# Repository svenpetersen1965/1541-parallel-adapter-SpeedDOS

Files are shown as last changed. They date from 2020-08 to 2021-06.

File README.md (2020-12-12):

# 1541-parallel-adapter-SpeedDOS
This is a reliable and easy to build parallel User Port Adapter for the Commodore 1541/1541-II for SpeedDOS

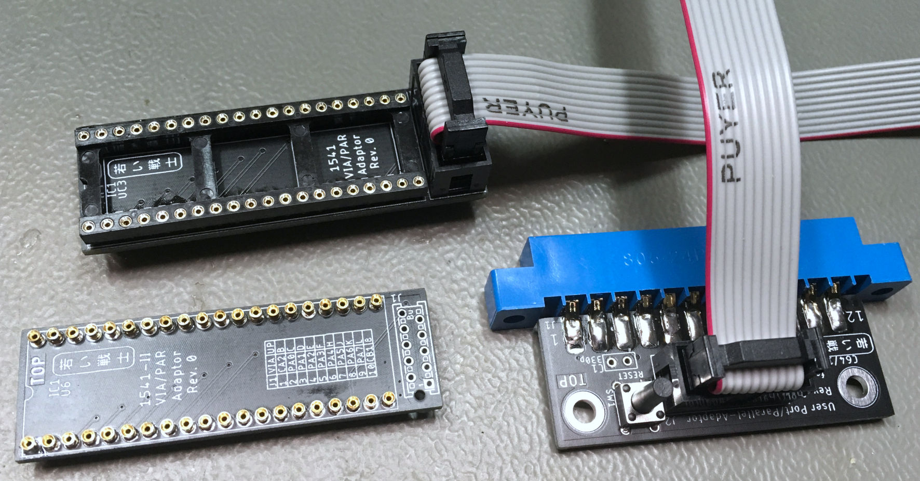
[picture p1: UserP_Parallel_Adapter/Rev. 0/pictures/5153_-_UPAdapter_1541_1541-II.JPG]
SpeedDOS parallel interface


The project consists out of a user port module with a 3D printed case, which also includes a RESET button for the C64. 

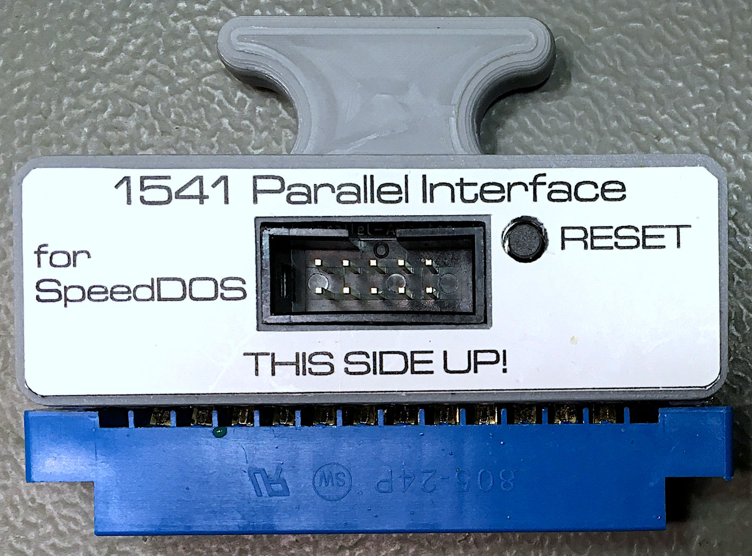
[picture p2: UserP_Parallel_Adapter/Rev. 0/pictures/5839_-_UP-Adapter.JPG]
SpeedDOS parallel interface


There are two different VIA adapters for the 1541 and a low profile one for the narrower sapce in the 1541-II.

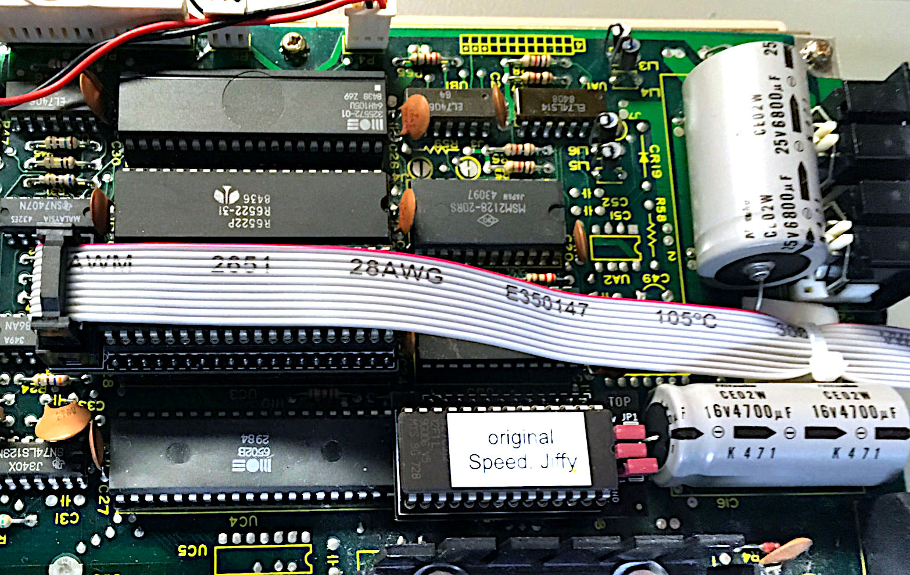
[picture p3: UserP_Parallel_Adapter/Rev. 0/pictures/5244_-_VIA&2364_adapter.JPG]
SpeedDOS VIA adapter 1541


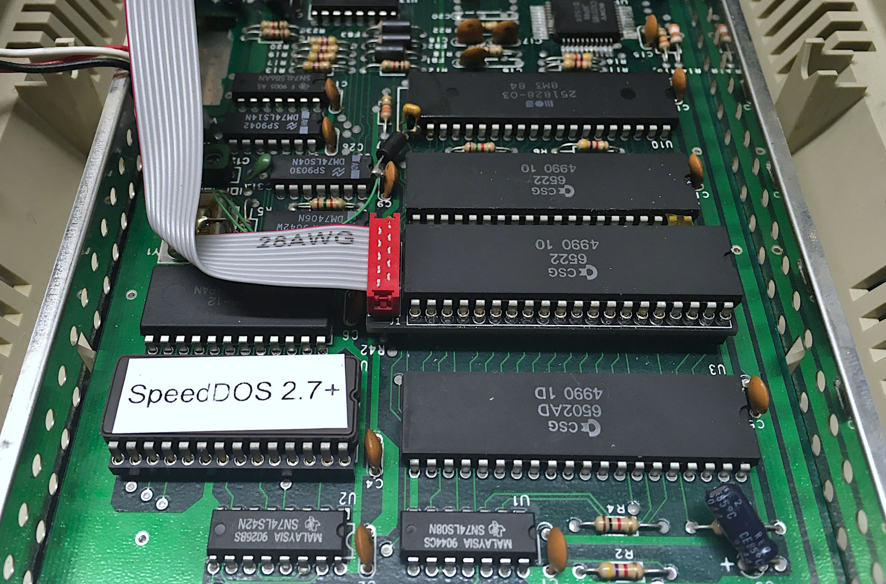
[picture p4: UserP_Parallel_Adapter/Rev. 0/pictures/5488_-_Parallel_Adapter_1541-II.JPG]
SpeedDOS VIA adapter 1541


BOM Values:
* 1541 Adapter (cable included): 4.91€ (28.06.2020)
* 1541-II Adapter (cable included): 3.30€ (10.12.2020)
* User Port Adapter (no case): 4.65€ (28.06.2020)

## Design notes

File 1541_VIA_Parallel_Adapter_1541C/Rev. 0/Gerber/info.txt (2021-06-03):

      
       Board: VIA_PAR_Adapter_1541C
       Rev.:  0
  
       Files:
       ======
  
       All Gerber files are generated in extended gerber format (RS274X)
       *.TOP        : Film top copper
       *.BOT        :  -"- bottom copper
       *.STC        :  -"- top soldermask 
       *.STS        :  -"- bottom soldermask
       *.PLC        :  -"- silk screen top
       *.PLS        :  -"- silk screen bottom
       *.DK         : Drills plated Through (Excellon)
       *.NDK        : Drills not plated Through (Excellon)
       *.OUT        : Board outline

       Board Size:
       ===========
       Length     :   65.0 mm
       Width      :   21.5 mm
       Thickness  :   1.6 mm
       Material   :   FR 4
       Copper     :   35 um
       Surface    :   HASL
       
       Remarks:
       ========
       minimum drill: 0.35mm
       minimum width: 8 mil
       minimum distance: 6 mil

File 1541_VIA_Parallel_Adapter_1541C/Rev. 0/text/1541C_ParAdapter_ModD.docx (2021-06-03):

Commodore 1541 VIA/Parallel-Adapter for 1541C Rev. 0

Module Description

# Introduction

This adapter board serves as a VIA (6522) adapter for a parallel connection for SpeedDOS in conjunction with a suitable ribbon cable and the User Port Parallel-Adapter (Project 150).

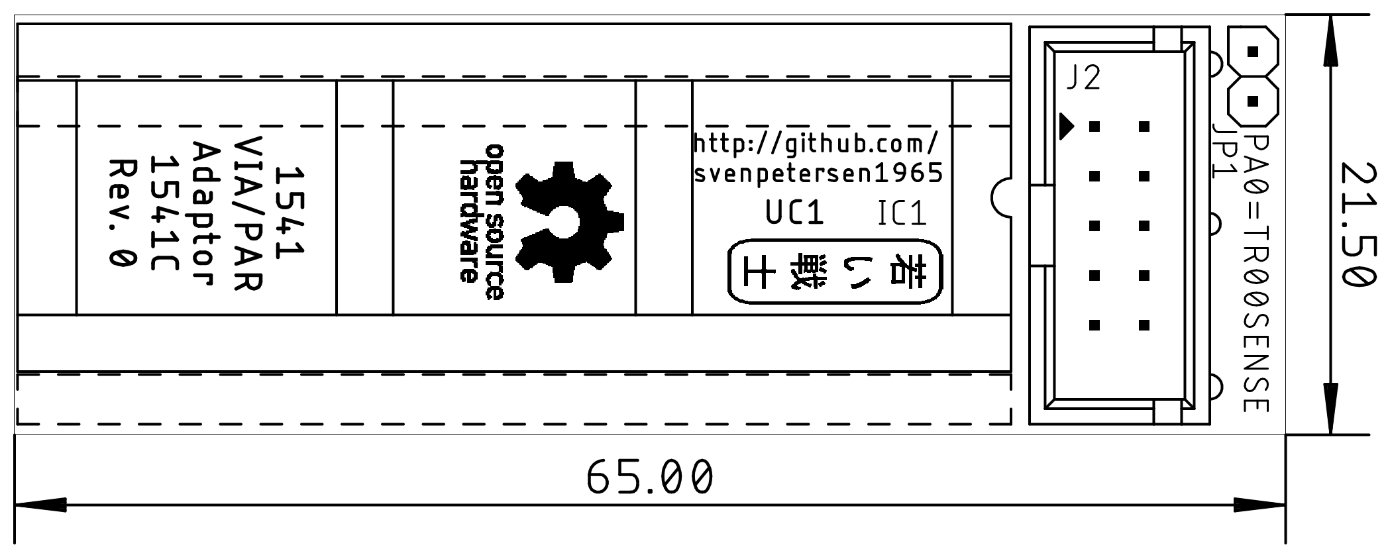
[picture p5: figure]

Figure 1: Dimensions

The box connector (2x5 way, 2.54mm pitch) has the following pinout:

VIA (pin) | J2 | J2 | VIA (pin)
CA2 (39) | 1 | 2 | PA0 (2)
PA1 (3) | 3 | 4 | PA2 (4)
PA3 (5) | 5 | 6 | PA4 (6)
PA5 (7) | 7 | 8 | PA6 (8)
PA7 (9) | 9 | 10 | CB1 (18)

The via for the parallel data transmission in a 1541C is UC1. The Jumper JP1 connects the signal PA0 to the signal TR00SENSE, which is (probably) required for the original firmware.

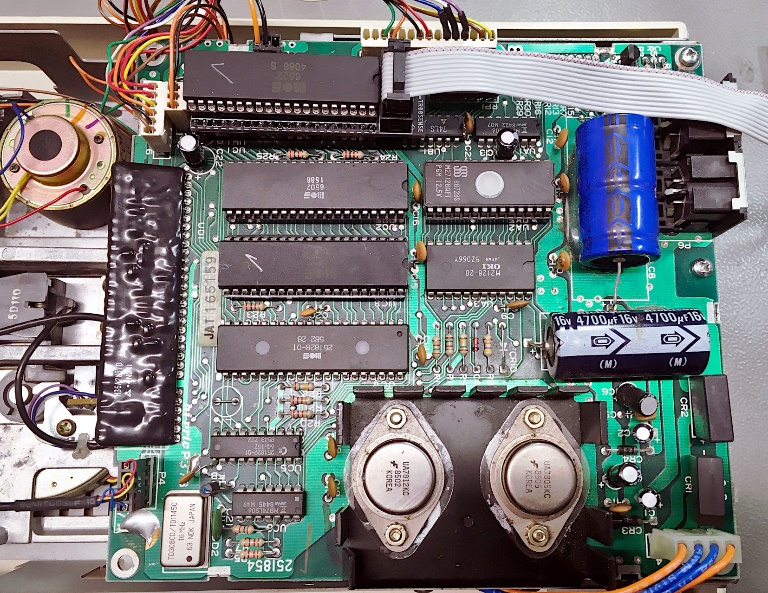
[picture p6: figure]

Figure 2: : VIA-Parallel-Adapter installed in a 1541C

# Installation

Three issues have to be taken care of, when installing the VIA-Parallel-Adapter:

- The VIA (UC1) should be socketed
- The adapter has to be oriented properly (align the notch of the IC, the adapter and the socket on the 1541C PCB
- The pins of box connector on the solder side must not make contact with any component leads

The latter issue can be caused by the leads of a 100n capacitor, which can be replaced with a smaller, modern capacitor. The adapter has to sit firmly in the socket, though.

The ribbon cable has two 2x5 (ribbon cable) IDC connectors. The one, that goes inside the 1541C is the one without a strain relief. The header connecting to the User Port Adapter does require the strain relief, though.

It is a good idea to secure the ribbon cable with an adhesive cable post and a cable tie for strain relief, after the configuration is fully functional. A ribbon cable exiting the case through the breakout for the fuse is pretty common, I did not experience any problems with it, but one person reported a possible source of problems, here.

An alternative way of exiting the case is the left side of the case. A breakout for the ribbon cable has to be filed into the case, though.

The cable making with IDC connectors does not require any special tools, except a (small) vice for compressing the connector after the ribbon cable was inserted properly. In case you don not feel comfortable with this work, consult this write up about cable making: http://tech.guitarsite.de/cable_making.html#Ribbon%20Cables

# Assembly

The Assembly of the VIA-Parallel-Adapter is fairly simple. The precision round pin headers on the solder side need to be aligned to be straight and in the proper distance. For this purpose, the cut strips have to be inserted into the DIP-socket before soldering. Their alignment needs to be checked. They should be fully inserted into the socket and the PCB should be perpendicular. After soldering the pin stripes, the DIP-40 socket can be removed and soldered in on the top side. Some of soldered pins of the pin strips might require to be shortened. The DIP-40 socket should sit straight on the PCB.

Finally, the box connector can be soldered.

The pins of the precision pin strips are pretty delicate and brittle. They should not be bent much, so care must be taken before and while installing them in the socket of the 1541. Square headers must not be used instead, because those might break the sockets and do not sit well in the socket, either.

# Revision History

## Rev. 0

- Prototypes preliminarily tested in a 1541.

1541C_ParAdapter_ModD.docx 07.05.2021 16:39 Drafted by Sven Petersen Page 2 of 2 Doc.-No.: 178-6-01-00

1541C_ParAdapter_ModD.docx 07.05.2021 16:39 Drafted by Sven Petersen Page 1 of 1 Doc.-No.: 000-6-00-00

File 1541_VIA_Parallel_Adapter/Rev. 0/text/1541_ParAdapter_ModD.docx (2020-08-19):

Commodore 1541 VIA/Parallel-Adapter Rev. 0

Module Description

# Introduction

This adapter board serves as a VIA (6522) adapter for a parallel connection for SpeedDOS in conjunction with a suitable ribbon cable and the User Port Parallel-Adapter (Project 150).

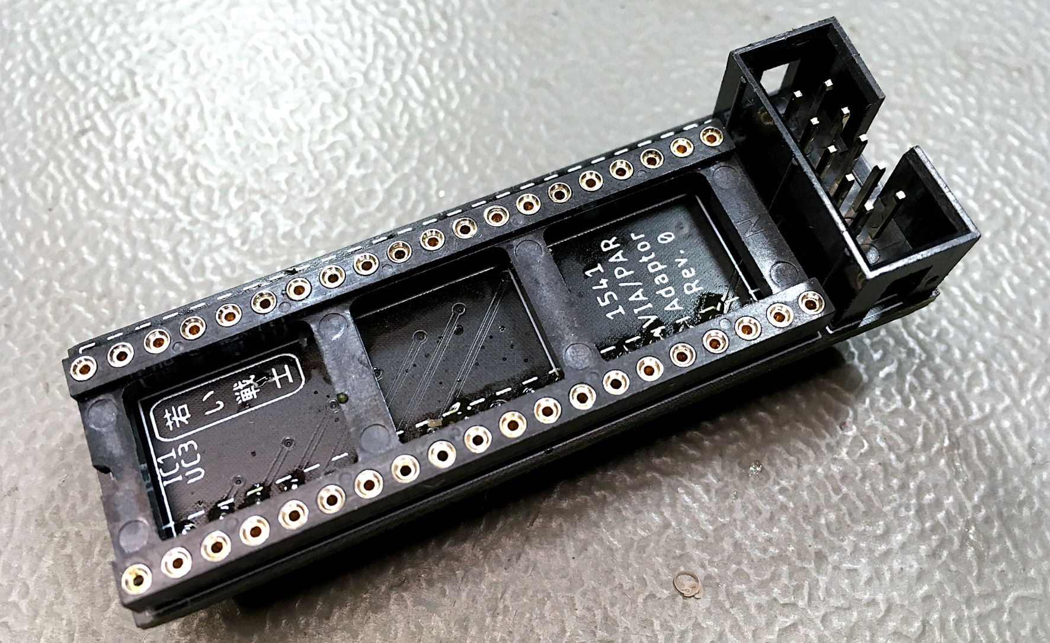
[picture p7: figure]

Figure 1: Commodore 1541 VIA/Parallel-Adapter

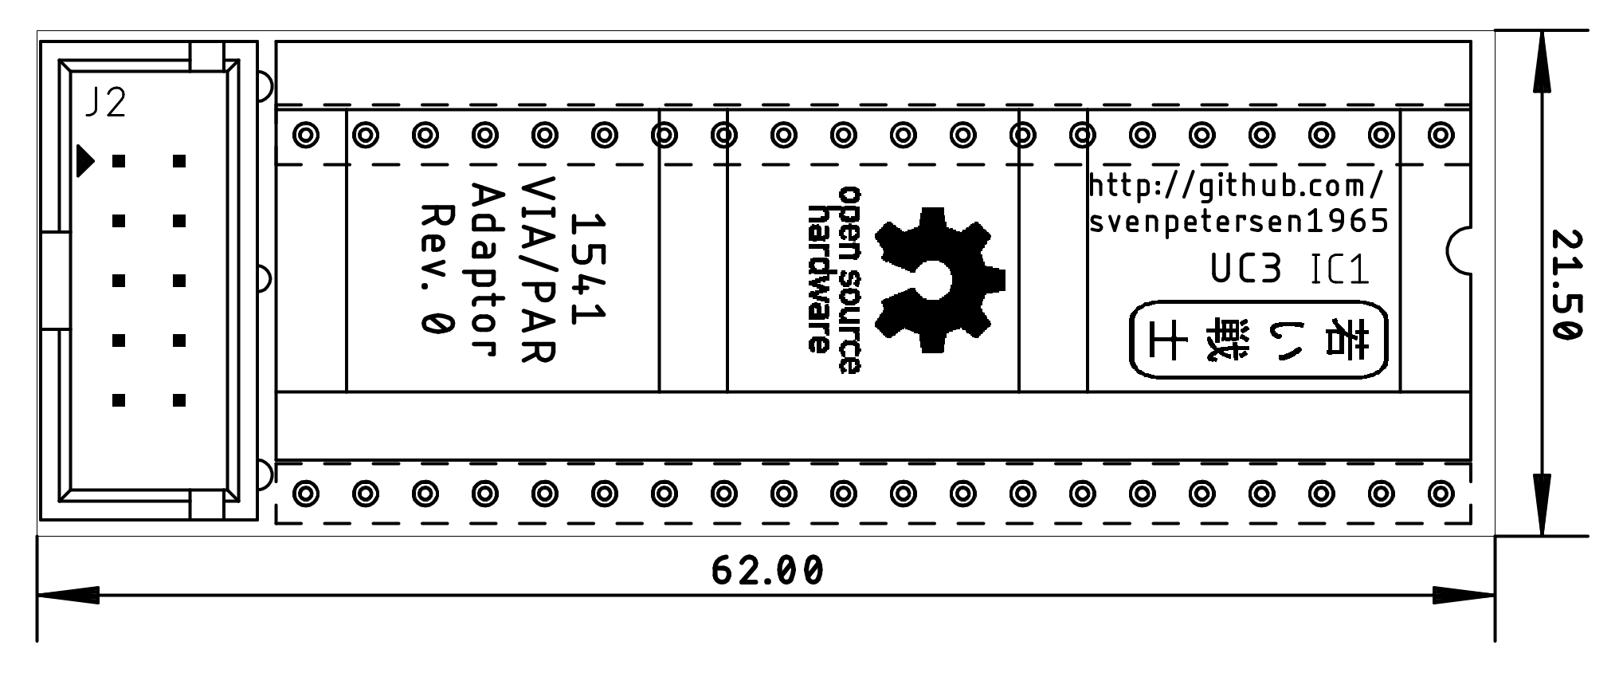
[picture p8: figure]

Figure 2: Dimensions

The box connector (2x5 way, 2.54mm pitch) has the following pinout:

VIA (pin) | J2 | J2 | VIA (pin)
CA2 (39) | 1 | 2 | PA0 (2)
PA1 (3) | 3 | 4 | PA2 (4)
PA3 (5) | 5 | 6 | PA4 (6)
PA5 (7) | 7 | 8 | PA6 (8)
PA7 (9) | 9 | 10 | CB1 (18)

The via for the parallel data transmission in a 1541 is UC3.

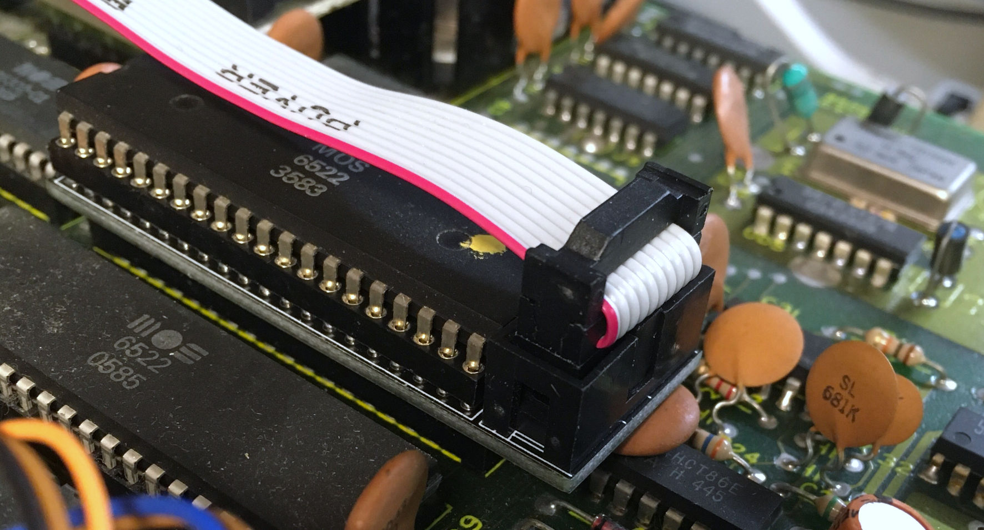
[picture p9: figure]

Figure 3: VIA-Parallel-Adapter installed in a 1541

# Installation

Three issues have to be taken care of, when installing the VIA-Parallel-Adapter:

- The VIA (UC3) should be socketed
- The adapter has to be oriented properly (align the notch of the IC, the adapter and the socket on the 1541 PCB
- The pins of box connector on the solder side must not make contact with any component leads

The latter issue can be caused by the leads of C28. This is a 100n capacitor, which can be replaced with a smaller, modern capacitor. In case it is a disc capacitor like in Figure 3, it can be bent over. The adapter has to sit firmly in the socket, though.

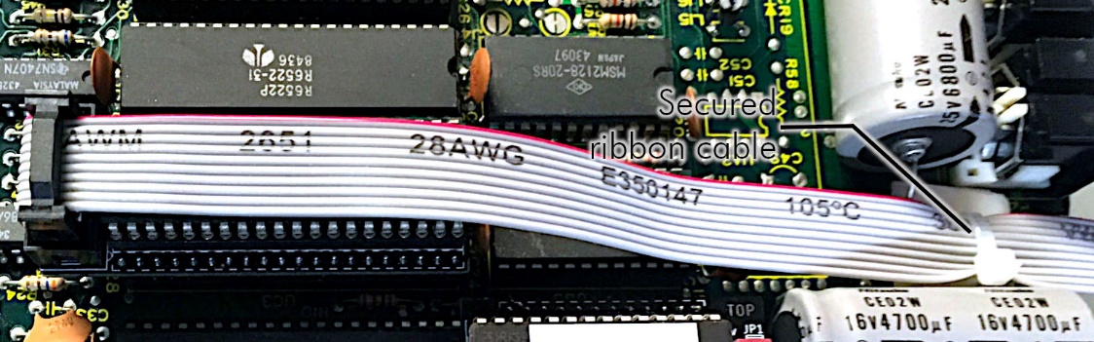
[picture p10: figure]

Figure 4: Secured ribbon cable

It is a good idea to secure the ribbon cable with an adhesive cable post and a cable tie for strain relief, after the configuration is fully functional (Figure 4). A ribbon cable exiting the case through the breakout for the fuse is pretty common, I did not experience any problems with it, but one person reported a possible source of problems, here.

An alternative way of exiting the case is the left side of the case. A breakout for the ribbon cable has to be filed into the case, though.

The cable making with IDC connectors does not require any special tools, except a (small) vice for compressing the connector after the ribbon cable was inserted properly. In case you don not feel comfortable with this work, consult this write up about cable making: http://tech.guitarsite.de/cable_making.html#Ribbon%20Cables

# Assembly

The Assembly of the VIA-Parallel-Adapter is fairly simple. The precision round pin headers on the solder side need to be aligned to be straight and in the proper distance. For this purpose, the cut strips have to be inserted into the DIP-socket before soldering. Their alignment needs to be checked. They should be fully inserted into the socket and the PCB should be perpendicular. After soldering the pin stripes, the DIP-40 socket can be removed and soldered in on the top side. Some of soldered pins of the pin strips might require to be shortened. The DIP-40 socket should sit straight on the PCB.

Finally, the box connector can be soldered.

The pins of the precision pin strips are pretty delicate and brittle. They should not be bent much, so care must be taken before and while installing them in the socket of the 1541. Square headers must not be used instead, because those might break the sockets and do not sit well in the socket, either.

# Revision History

## Rev. 0

- Prototypes fully functional. For testing consult the documentation of the User Port/Parallel Adapter (Project 150).

1541_ParAdapter_ModD.docx 19.08.2020 14:08 Drafted by Sven Petersen Page 2 of 2 Doc.-No.: 148-6-01-00

1541_ParAdapter_ModD.docx 19.08.2020 14:08 Drafted by Sven Petersen Page 1 of 1 Doc.-No.: 000-6-00-00

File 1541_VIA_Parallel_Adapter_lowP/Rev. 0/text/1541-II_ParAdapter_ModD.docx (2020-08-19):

Commodore 1541-II VIA/Parallel-Adapter Rev. 0

Module Description

# Introduction

This adapter board serves as a VIA (6522) adapter for a parallel connection for SpeedDOS in conjunction with a suitable ribbon cable and the User Port Parallel-Adapter (Project 150).

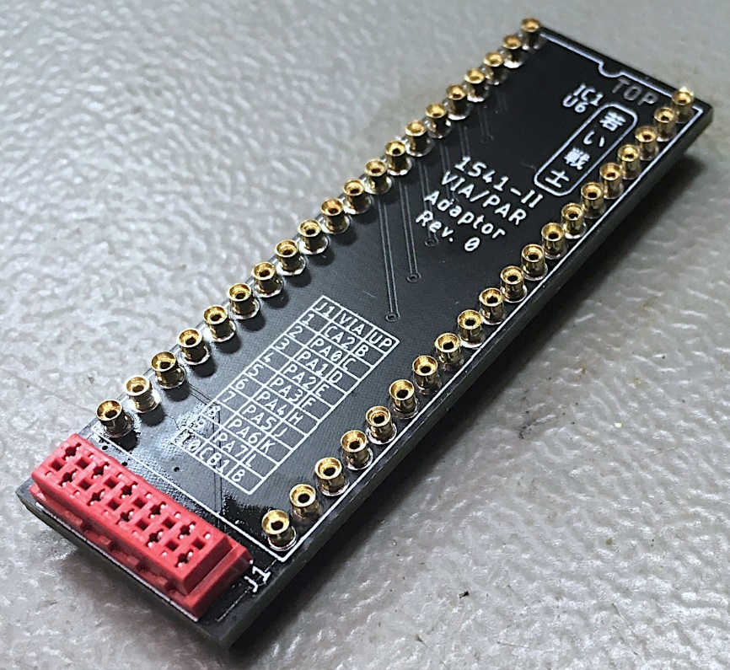
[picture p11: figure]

Figure 1: Commodore 1541-II VIA/Parallel-Adapter

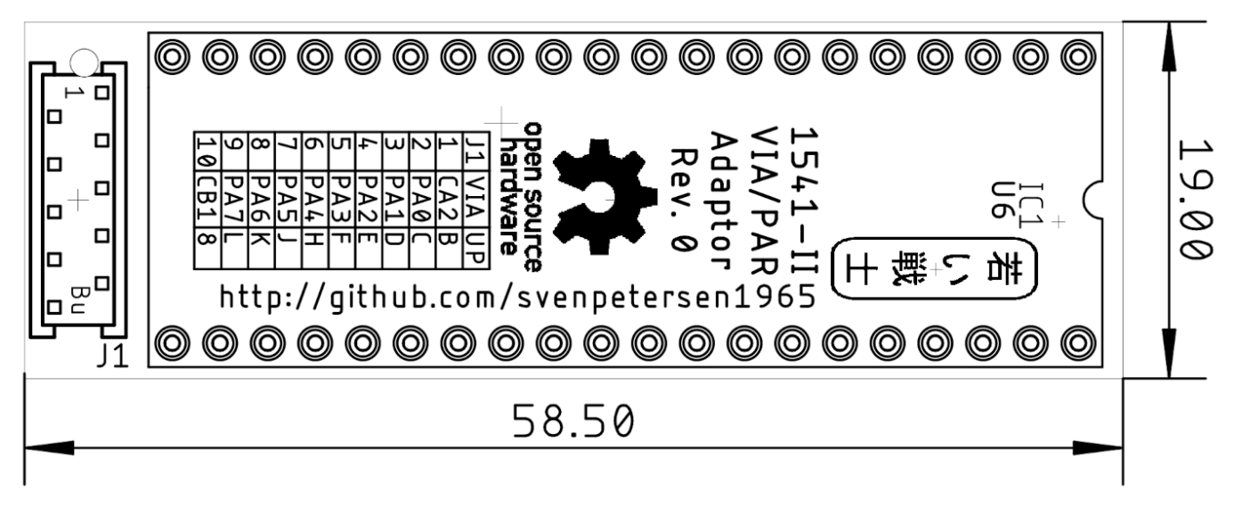
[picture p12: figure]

Figure 2: Dimensions

The microMatch connector (10 way) has the following pinout:

VIA (pin) | J2 | J2 | VIA (pin)
CA2 (39) | 1 | 2 | PA0 (2)
PA1 (3) | 3 | 4 | PA2 (4)
PA3 (5) | 5 | 6 | PA4 (6)
PA5 (7) | 7 | 8 | PA6 (8)
PA7 (9) | 9 | 10 | CB1 (18)

The via for the parallel data transmission in a 1541 is U6.

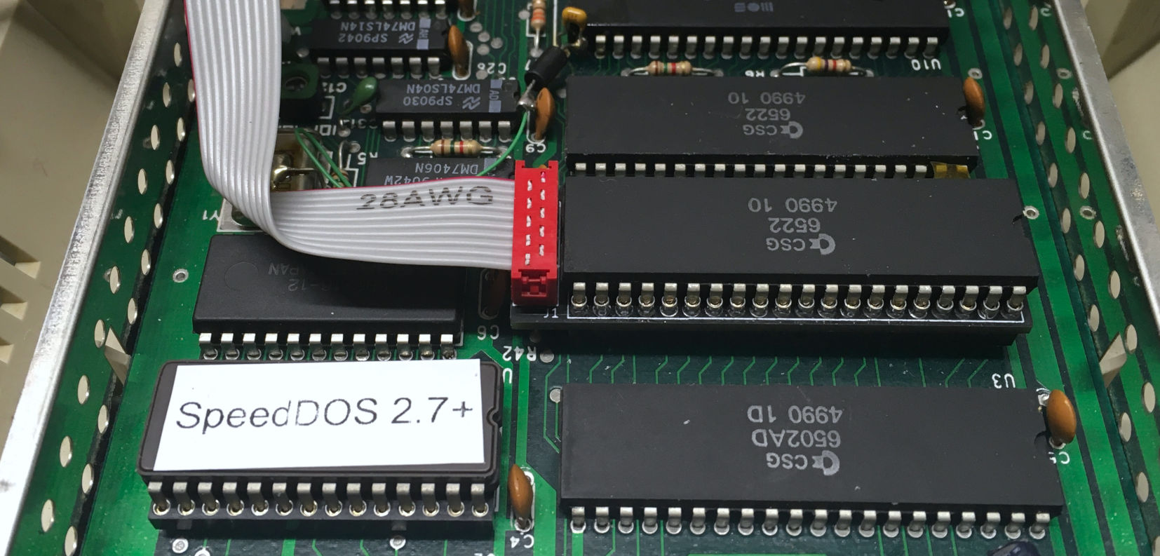
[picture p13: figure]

Figure 3: VIA-Parallel-Adapter installed in a 1541-II

# Installation

Four issues have to be taken care of, when installing the VIA-Parallel-Adapter:

- The VIA (U6) should be socketed
- The adapter has to be oriented properly (align the notch of the IC, the adapter and the socket on the 1541-II PCB
- The pins of microMatch connector on the solder side must not make contact with any component leads.
- Pin 2 (PA0) of U6 is connected to GND, which is not required for proper operation (not even with the original Kernal!). This prevents a proper function of the parallel adapter. Pin 2 must either be cut off, filed down (a bit) and insulated (Figure 4) or the trace between pin 1 and pin 2 of U6 must be cut.

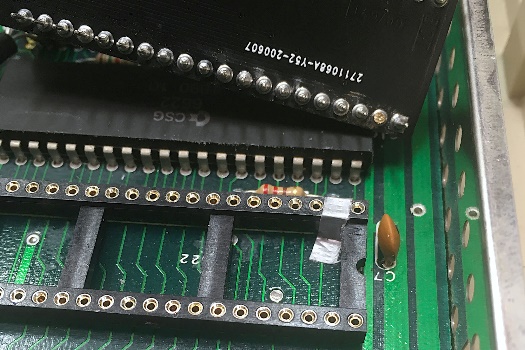
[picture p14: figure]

Figure 4: Shortened pin 2 and insulated socket

It is a good idea to secure the ribbon cable with an adhesive cable post and a cable tie for strain relief, after the configuration is fully functional. A ribbon cable exiting the case through the breakout for the fuse is pretty common, I did not experience any problems with it, but one person reported a possible source of problems, here.

An alternative way of exiting the case is the left side of the case. A breakout for the ribbon cable has to be filed into the case, though.

The cable making with IDC connectors does not require any special tools, except a (small) vice for compressing the connector after the ribbon cable was inserted properly. In case you don not feel comfortable with this work, consult this write up about cable making: http://tech.guitarsite.de/cable_making.html#Ribbon%20Cables

# Assembly

The low-profile property of the adapter requires precision round pin sockets. They are usually pretty hard to source and expensive. In July 2020, they were about $10 plus shipping for 50 each on Ebay USA. It is pretty cheap and easy to salvage them from a precision pin DIP-40 socket (40 pin sockets for less than $1!). The pin sockets can be popped out of a precision pin socket by applying slight pressure from the bottom side on the “shoulders” of the pin socket with a suitable tweezer (Figure 5). This takes less than 2 minutes per 40 pins.

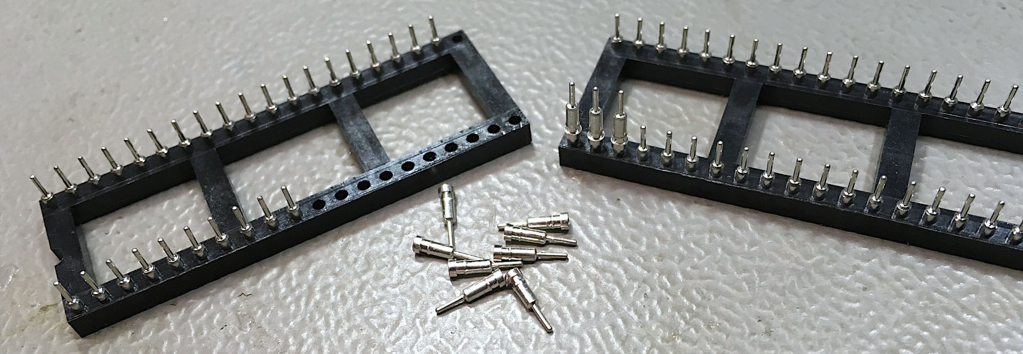
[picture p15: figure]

Figure 5: Salvaging the pin sockets

For proper soldering, the pin sockets need to be aligned. This is accomplished by plugging each on the pin side of a 2nd DIP-40 precision round pin socket (Figure 6). It has t be checked, that all pins are fully inserted. The pins can now be inserted into the solder pads of the PCB from the top side.

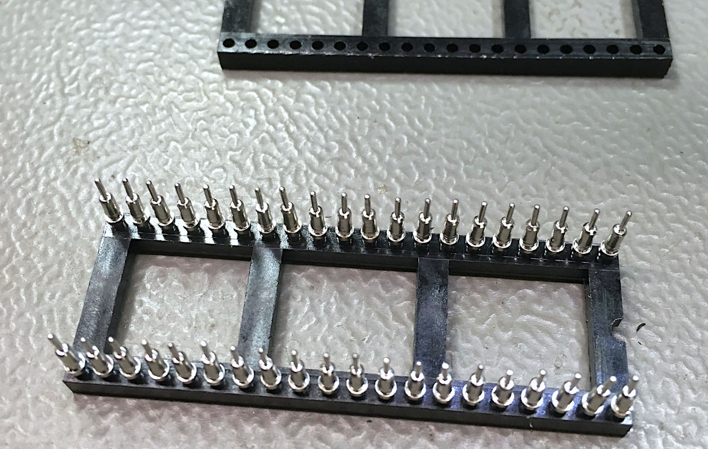
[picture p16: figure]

Figure 6: Alignment of the pin sockets

After making sure, that everything is straight (Figure 7), the pins can be soldered from the solder side.

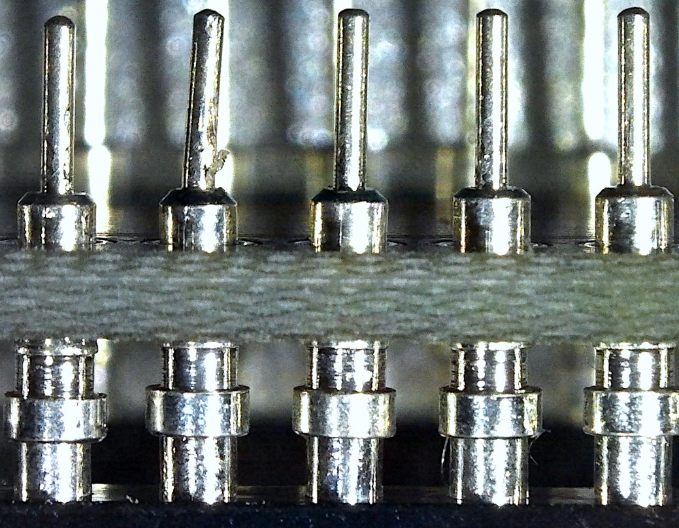
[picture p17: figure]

Figure 7: Pin sockets aligned in PCB before soldering

Just add very little solder, so that it just coats the gap between pin socket and solder pad and a meniscus is formed. A smooth, concave meniscus indicates a good wetting (Figure 8).

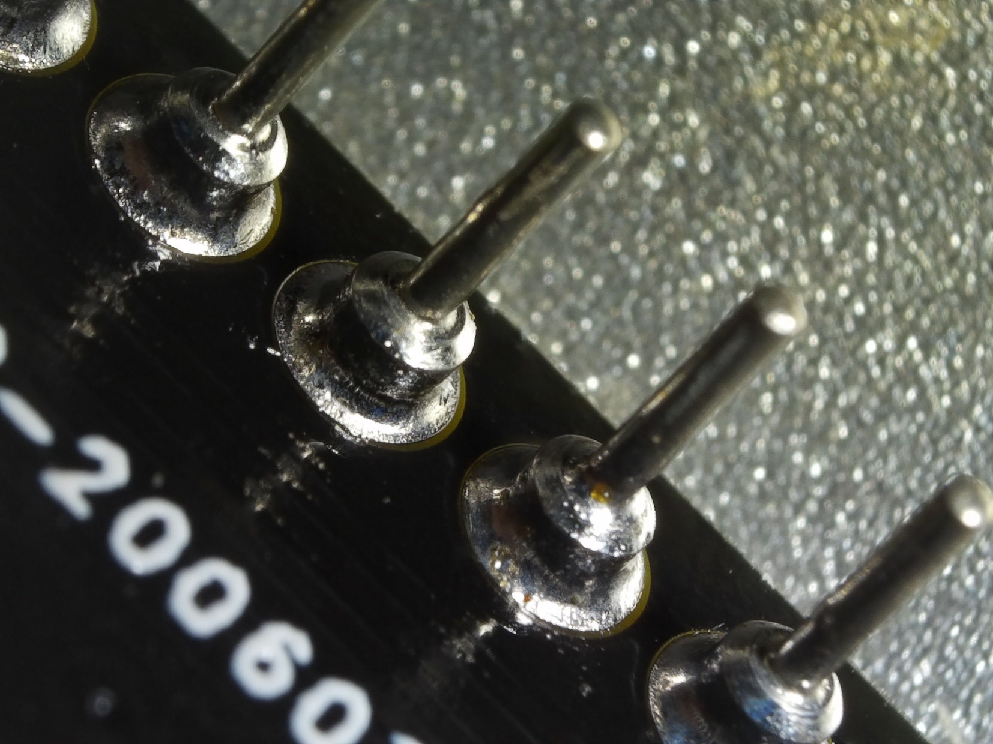
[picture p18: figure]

Figure 8: Amount of solder and meniscus of the bottom pads

It is desired that the solder is rising through the pad and also forms a meniscus on the component side (Figure 9). Care must be taken, that the shoulder of the pin sockets is not coated with solder.

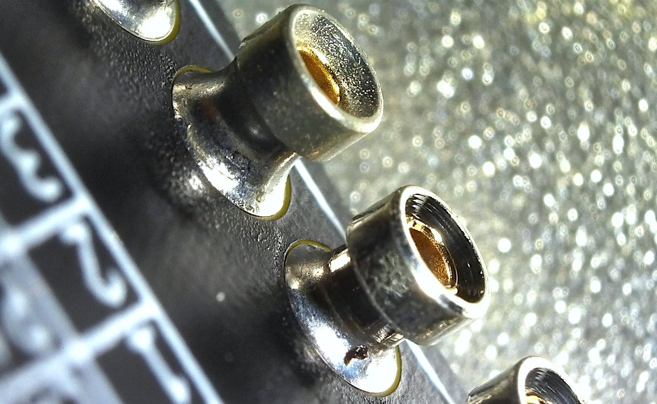
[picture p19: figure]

Figure 9: Solder meniscus on the top solder pads

Finally, the microMatch connector can be soldered.

# Revision History

## Rev. 0

- Prototypes fully functional. For testing consult the documentation of the User Port/Parallel Adapter (Project 150).

1541-II_ParAdapter_ModD.docx 19.08.2020 20:41 Drafted by Sven Petersen Page 2 of 2 Doc.-No.: 149-6-01-00

1541-II_ParAdapter_ModD.docx 19.08.2020 20:41 Drafted by Sven Petersen Page 1 of 1 Doc.-No.: 000-6-00-00

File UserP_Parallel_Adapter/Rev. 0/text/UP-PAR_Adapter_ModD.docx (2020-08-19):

User Port/Parallel Adapter for Commodore 1541/1541-II Rev. 0

Module Description

# Introduction

Some speed-loaders for the C64 make use of a parallel data transfer for communicating with the Commodore 1541 or 1541-II floppy disk drive. This is possible, because in both FDDs a complete port (PAx) and two hand shake pins (CA2, CB1) of the 2nd VIA (6522) are not used.

SpeedDOS utilizes this fact and uses a ribbon cable between the VIA and the User Port.

Very often, the ribbon cable has been attached to an extra DIP40 socket, which it is soldered to, that fits between the original socket and the VIA. This ribbon cable is then connected to an edge connector for the user port. This is a cheap solution, which is not very reliable. A wire can be torn off the socket or the ribbon cable gets old and brittle etc.

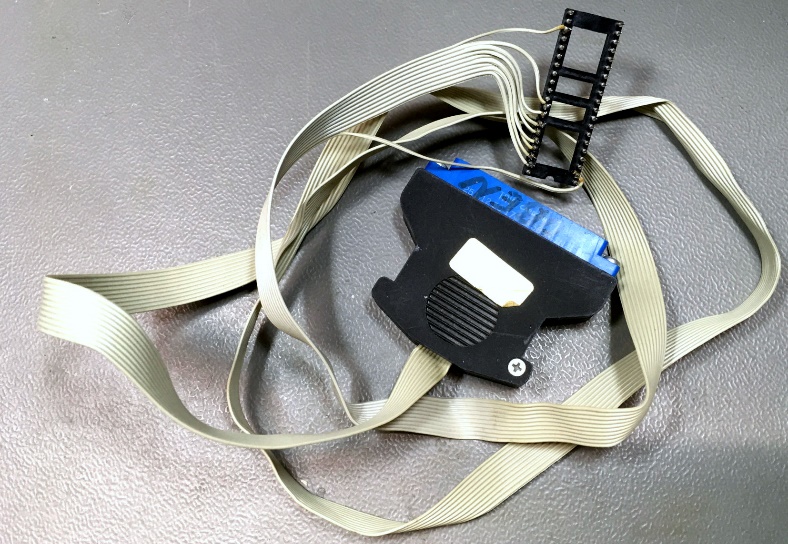
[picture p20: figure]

Figure 1: Traditional Parallel Cable

The User Port Adapter provides a solution with an easy to make and easy to replace cable. The risk of a wrong assembly is little. It works in conjunction with a dedicated VIA adapter for the 1541 and a low-profile adapter for the 1541-II.

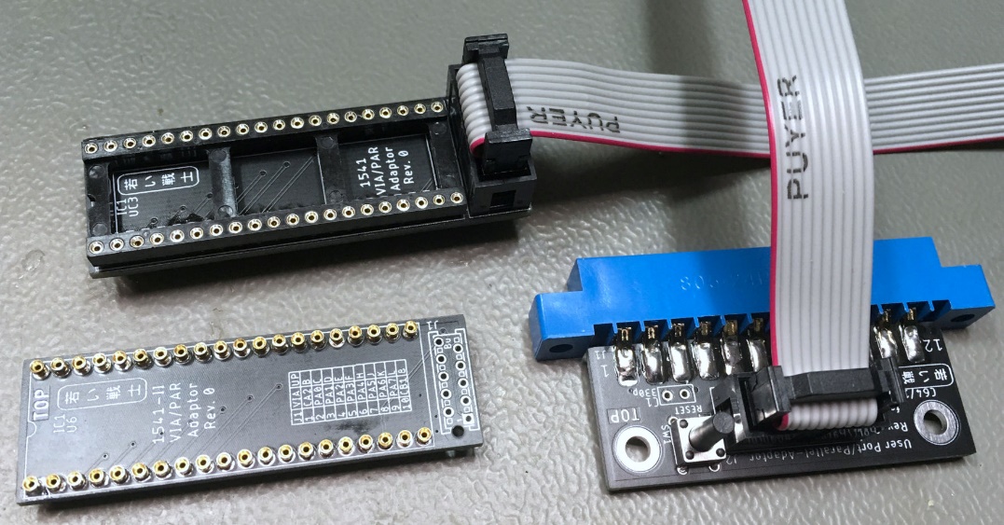
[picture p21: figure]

Figure 2: User Port Parallel Adapter and both sorts of VIA Adapters

The connections between the user port and the VIA for SpeedDOS are defined like this:

UP (pin) | VIA (pin) | J2 | J2 | VIA (pin) | UP (pin)
(B) | CA2 (39) | 1 | 2 | PA0 (2) | PB0 (C)
PB1 (D) | PA1 (3) | 3 | 4 | PA2 (4) | PB2 (E)
PB3 (F) | PA3 (5) | 5 | 6 | PA4 (6) | PB4 (H)
PB5 (J) | PA5 (7) | 7 | 8 | PA6 (8) | PB6 (K)
PB7 (L) | PA7 (9) | 9 | 10 | CB1 (18) | (8)

In the 1541, the used VIA is UC3, in the 1541-II, the VIA is U6.

The User Port parallel adapter provides a RESET button and also two capacitors between CA2 and GND and between CB1 and GND. Those capacitors are recommended to improve problems due to crosstalk here: http://pitsch.de/stuff/c64/index_floppy.htm#B1.3.

Crosstalk problems were not experienced while testing without the capacitors, they do not cause problems, either, so they are at least an option.

# Dimensions

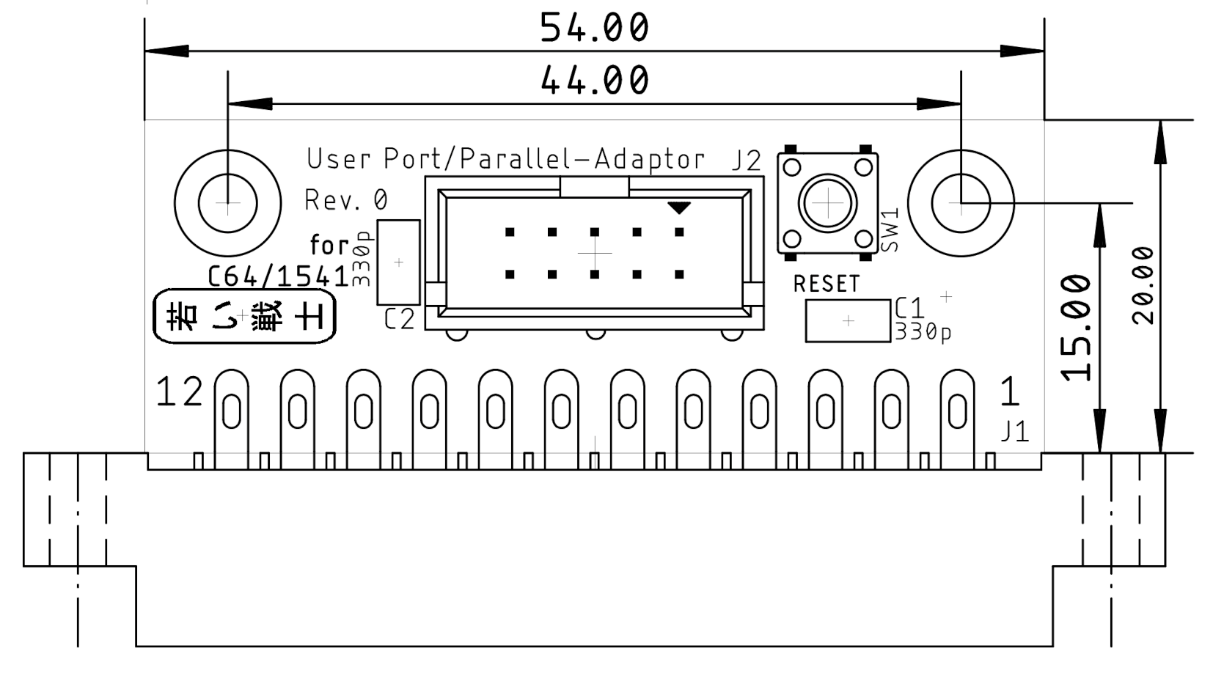
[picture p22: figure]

Figure 3: Dimensions of the User Port Parallel Adapter

# Case


Figure 4: User Port Adapter in a 3D-printed case

# Annotations

SpeedDOS requires a special Software in the 1541 and 1541-II floppy disk drive. While the 1541-II accepts a 27C128 EPROM, the EPROM of the 1541 is a 2364 type, which requires an adapter. The Long Board Kernal Adapter (https://github.com/svenpetersen1965/C64-Kernal-Adapter-Switch-Long-Board) can serve this purpose. The height is not critical in the 1541, but installing a vertical pin header instead of a 90° type is recommended.

The cable making is pretty simple. Both ends of the cable are connected to IDC type connectors, which means, a small vice is a sufficient tool for attaching the connectors to the ribbon cable. In case you are not familiar with this work, please consult my article about cable making: http://tech.guitarsite.de/cable_making.html#Ribbon%20Cables

# Revision History

## Rev. 0

- Prototype (fully functional)

UP-PAR_Adapter_ModD.docx 19.08.2020 10:40 Drafted by Sven Petersen Page 2 of 2 Doc.-No.: 150-6-01-00

UP-PAR_Adapter_ModD.docx 19.08.2020 10:40 Drafted by Sven Petersen Page 1 of 1 Doc.-No.: 150-6-01-00

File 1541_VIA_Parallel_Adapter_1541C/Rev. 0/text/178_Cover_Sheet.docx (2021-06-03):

Project Documentation

Commodore 1541 VIA/Parallel-Adapter

Project number: 178

Revision: 0

Date: 10.04.2021

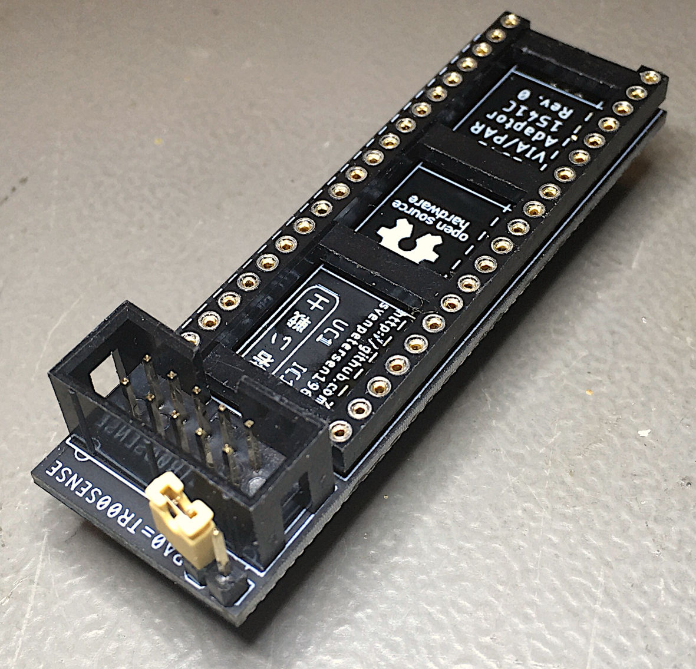
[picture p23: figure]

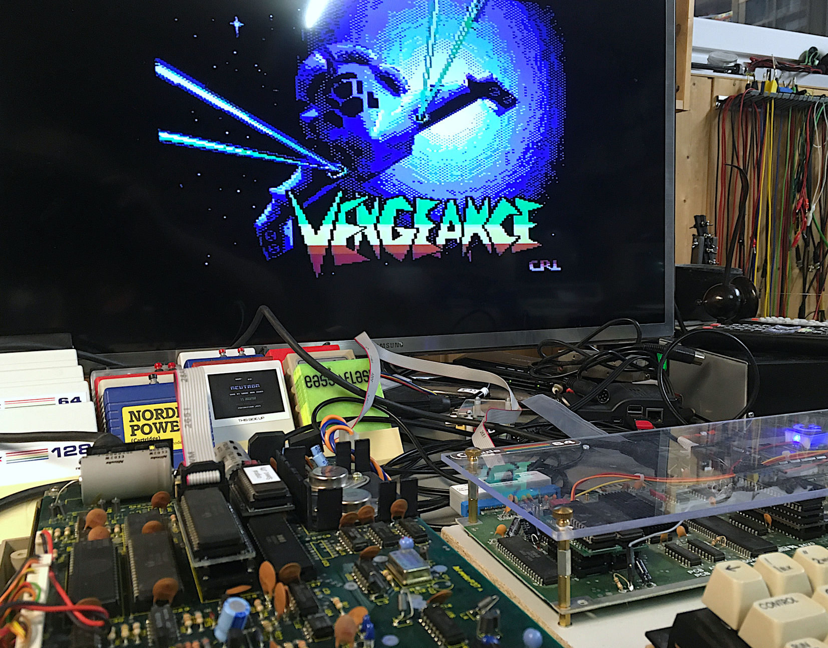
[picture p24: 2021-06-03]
1541_VIA_Parallel_Adapter_1541C/Rev. 0/pictures/8389_-_Vengeance.JPG

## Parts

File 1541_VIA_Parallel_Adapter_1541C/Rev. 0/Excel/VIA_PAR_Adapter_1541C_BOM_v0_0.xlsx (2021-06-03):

Commodore 1541 VIA/Parallel-Adapter for 1541C Rev. 0
Bill of Material Rev. 0.0
Pos. | Qty | Value | Footprint | Ref.-No. | Comment
1 | 1 | 178-2-01-00 | 2 Layer | PCB Rev. 0 | 2 layer, Cu 35µ, HASL, 65.0mm x 21.5mm, 1.6mm FR4
2 | 1 | 2x5 box connector | 2X05WV | J2 | e.g. Reichelt WSL 10G
3 | 1 | two Pinstrip, precision round pins, cut to 20 pins length | DIL40_PINS_SS | J1 | Precision Round pins mandatory! E.g. Reichelt BKL 10120540 or
4 |  |  |  |  | 10PCS Single Row 40Pin 2.54mm Round Male Pin Header machined (https://www.ebay.de/itm/10PCS-Single-Row-40Pin-2-54mm-Round-Male-Pin-Header-machined/281821698031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)
5 | 1 | 40p DIP Socket | GS40P | IC1 | Dual In Line Socket, e.g. Reichelt: GS40P
6 | 1 | Pinheader 2.54mm |  | JP1 | optional for original firmaware
7 | 1 | Jumper 2.54mm |  | (JP1) | optional for original firmaware
8 | 2 | 10p IDC receptable, 2,54mm |  | (J2) | e.g. Reichelt RND 205-00682
9 | 1m | 10p/AWG28/1,27mm |  |  | Ribbon cable. See drawing 148-3-01-**

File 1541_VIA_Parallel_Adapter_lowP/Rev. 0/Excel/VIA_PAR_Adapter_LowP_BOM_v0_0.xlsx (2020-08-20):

Commodore 1541-II VIA/Parallel-Adapter Rev. 0
Bill of Material Rev. 0.0
Pos. | Qty | Value | Footprint | Ref.-No. | Comment
1 | 1 | 149-2-01-00 | 2 Layer | PCB Rev. 0 | 2 layer, Cu 35µ, HASL, 58.5 x 19mm, 1.6mm FR4
2 | 2 | 40p DIP Socket | GS40P | IC1 | Dual In Line precision round pin Socket, e.g. Reichelt: GS40P (the 2nd socket is for alignment), single pins: Connfly DS1005-09-468, tme.eu: STS-1P
3 | 1 | 8-215079-0 | MicroMaTch 10p | J1 | Tyco/AMP or MPE Garry 369-1-010, e.g. Reichelt MPE 369-1-010
4 | 1 | 8-215083-0 | MicroMaTch 10p | (J1) | Tyco/AMP (IDC connector) or MPE Garry 372-1-010, , e.g. Reichelt MPE 372-1-010
5 | 1 | 10p IDC receptacle, 2,54mm |  |  | e.g. Reichelt RND 205-00682
6 | 1m | 10p/AWG28/1,27mm |  |  | Ribbon cable. See drawing 149-3-01-**

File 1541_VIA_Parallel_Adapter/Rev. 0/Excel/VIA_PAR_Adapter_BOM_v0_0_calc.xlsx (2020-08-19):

Commodore 1541 VIA/Parallel-Adapter Rev. 0
Bill of Material Rev. 0.0
Pos. | Qty | Value | €/ea | € | Comment
1 | 1 | 148-2-01-00 | 1.00 € | 1.00 € | 2 layer, Cu 35µ, HASL, 62.0mm x 21.5mm, 1.6mm FR4
2 | 1 | 2x5 box connector | 0.10 € | 0.10 € | e.g. Reichelt WSL 10G
3 | 1 | two Pinstrip, precision round pins, cut to 20 pins length | 1.99 € | 1.99 € | Precision Round pins mandatory! E.g. Reichelt BKL 10120540 or
 |  |  |  |  | 10PCS Single Row 40Pin 2.54mm Round Male Pin Header machined (https://www.ebay.de/itm/10PCS-Single-Row-40Pin-2-54mm-Round-Male-Pin-Header-machined/281821698031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)
4 | 1 | 40p DIP Socket | 0.62 € | 0.62 € | Dual In Line Socket, e.g. Reichelt: GS40P
5 | 2 | 10p IDC receptable, 2,54mm | 0.10 € | 0.20 € | e.g. Reichelt RND 205-00682
6 | 1m | 10p/AWG28/1,27mm | 1.00 € | 1.00 € | Ribbon cable
 |  |  | Total | 4.91 €

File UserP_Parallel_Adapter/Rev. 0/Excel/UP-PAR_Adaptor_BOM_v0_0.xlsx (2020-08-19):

User Port Parallel Adapter Rev. 0
Bill of Material Rev. 0.0
Pos. | Qty | Value | Footprint | Ref.-No. | Comment
1 | 1 | 150-2-01-00 | 2 Layer | PCB Rev. 0 | 2 layer, Cu 35µ, HASL, 54.0mm x 20.0mm , 1.6mm FR4
 | 1 | 2x5 box connector | 2X05WV | J2 | e.g. Reichelt WSL 10G
 | 2 | 330p | C-2,5 | C1, C2 | Ceramic Cap, 2.5mm pitch,
 | 1 | 2x12, 3.96mm pitch | USERPORT | J1 | edge connector, C64 user port
 | 1 | tact switch 6x6mm, h=9.5mm | JTP-1130 | SW1 | e.G. Reichelt TASTER 3301B

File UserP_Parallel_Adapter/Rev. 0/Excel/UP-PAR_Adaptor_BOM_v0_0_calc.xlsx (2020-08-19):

User Port Parallel Adapter Rev. 0
Bill of Material Rev. 0.0
Pos. | Qty | Value | €/ea | € | Comment
1 | 1 | 150-2-01-00 | 1.00 € | 1.00 € | 2 layer, Cu 35µ, HASL, 54.0mm x 20.0mm , 1.6mm FR4
2 | 1 | 2x5 box connector | 0.10 € | 0.10 € | e.g. Reichelt WSL 10G
3 | 2 | 330p | 0.20 € | 0.40 € | Ceramic Cap, 2.5mm pitch,
4 | 1 | 2x12, 3.96mm pitch | 3.00 € | 3.00 € | edge connector, C64 user port
5 | 1 | tact switch 6x6mm, h=9.5mm | 0.15 € | 0.15 € | e.G. Reichelt TASTER 3301B
 |  |  | Total | 4.65 €

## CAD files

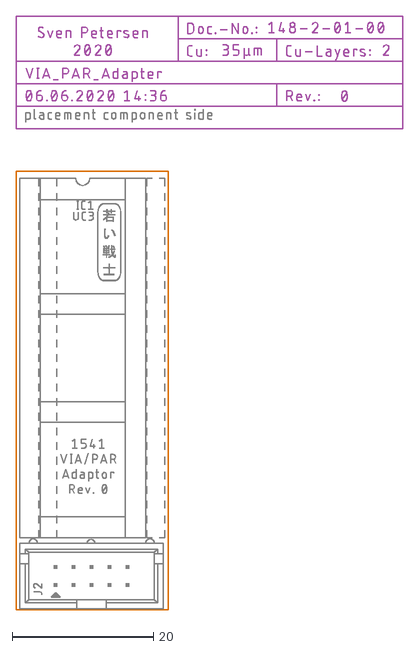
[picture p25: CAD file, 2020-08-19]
1541_VIA_Parallel_Adapter/Rev. 0/dxf/VIA_PAR_Adapter.dxf
54.6 x 83.9

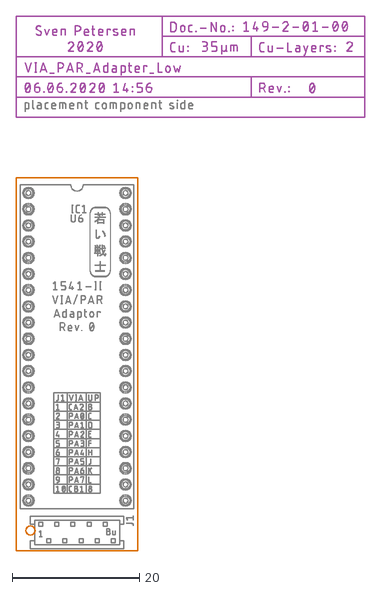
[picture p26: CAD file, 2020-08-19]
1541_VIA_Parallel_Adapter_lowP/Rev. 0/dxf/VIA_PAR_Adapter_Low.dxf
54.6 x 83.9

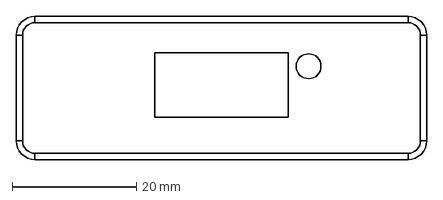
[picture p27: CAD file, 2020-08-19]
UserP_Parallel_Adapter/case/dxf/SpeedDOS_ParUP v1 Sheet1.dxf
66.0 x 23.0 mm

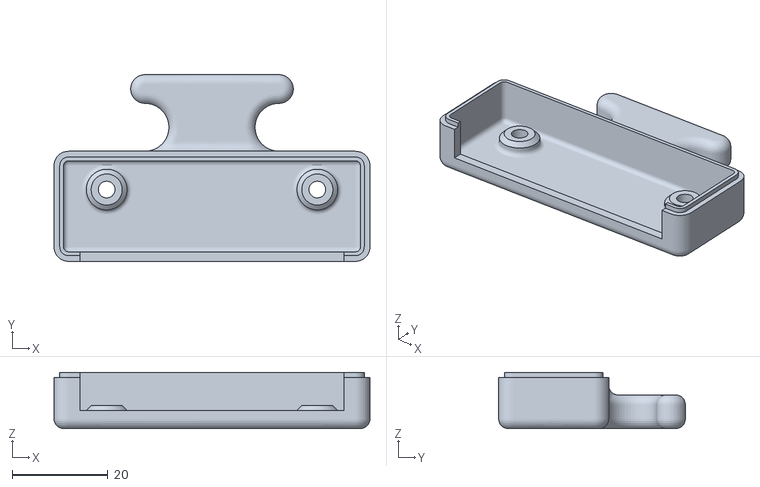
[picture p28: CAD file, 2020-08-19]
UserP_Parallel_Adapter/case/stl/UPPar_bottom_shell.stl
66.0 x 39.0 x 11.7

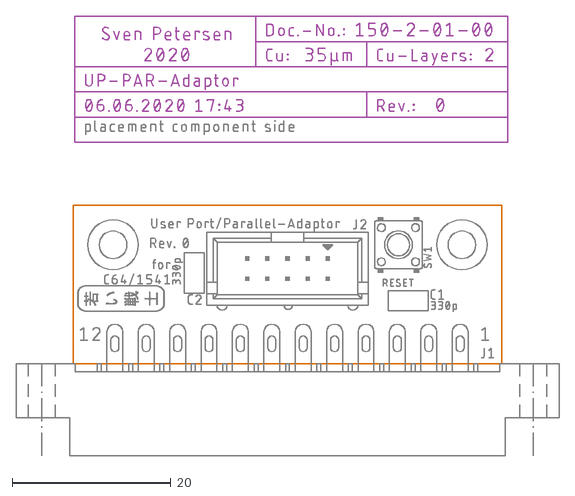
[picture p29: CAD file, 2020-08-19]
UserP_Parallel_Adapter/Rev. 0/dxf/UP-PAR-Adaptor.dxf
68.5 x 55.4

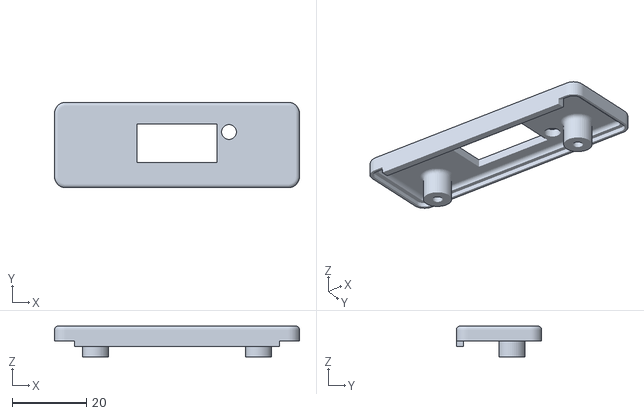
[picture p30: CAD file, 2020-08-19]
UserP_Parallel_Adapter/case/stl/UPPar_top_shell.stl
66.0 x 23.0 x 8.30

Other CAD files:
UserP_Parallel_Adapter/case/Fusion360/SpeedDOS_ParUP v5.f3d

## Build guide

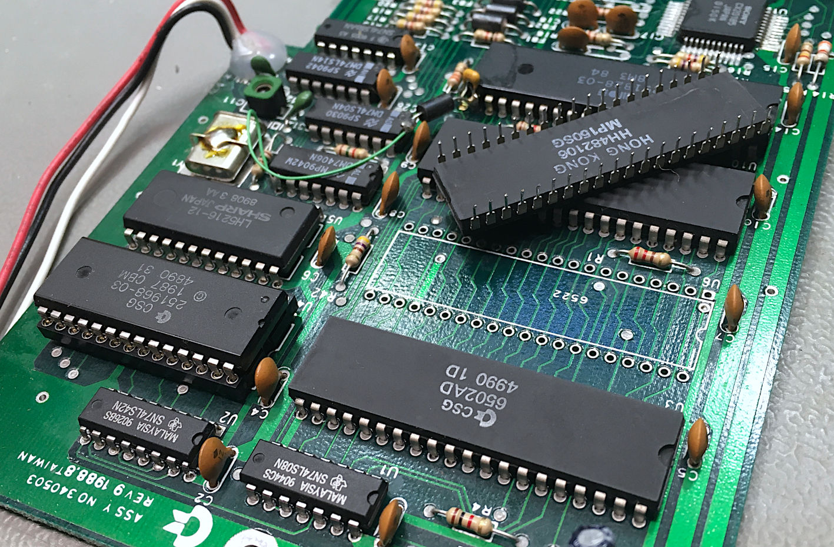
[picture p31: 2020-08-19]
1541_VIA_Parallel_Adapter_lowP/Rev. 0/pictures/5358_-_unsoldered_VIA.JPG

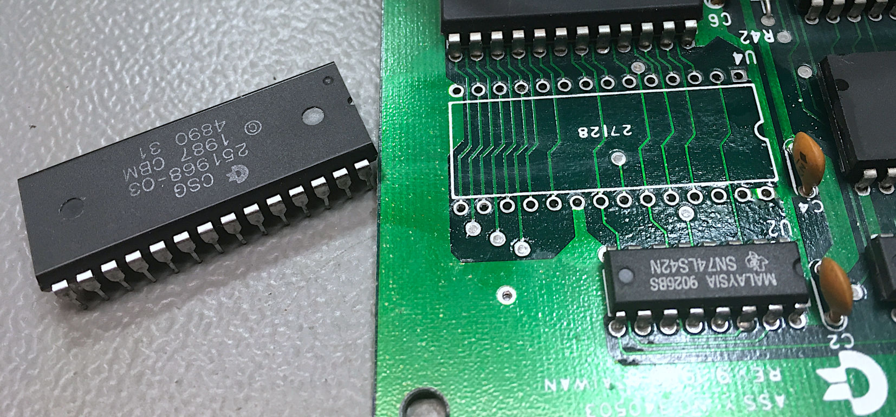
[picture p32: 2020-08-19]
1541_VIA_Parallel_Adapter_lowP/Rev. 0/pictures/5261_-_unsoldered_kernal_ROM.JPG

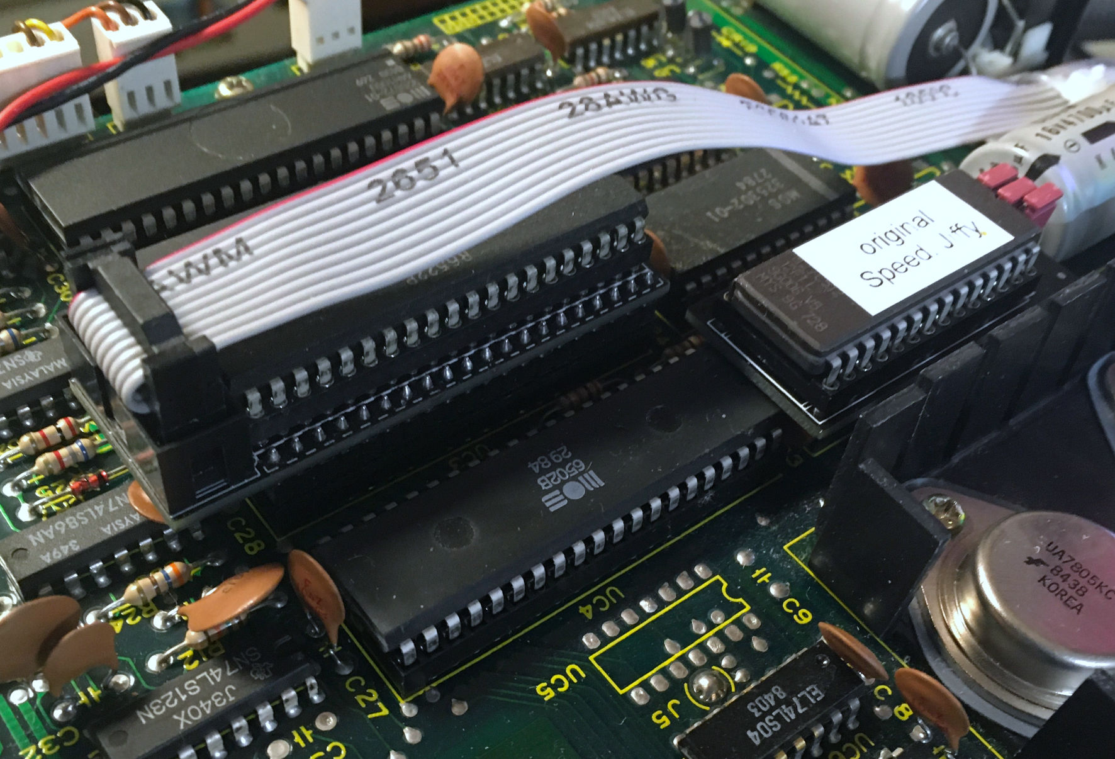
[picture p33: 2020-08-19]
1541_VIA_Parallel_Adapter/Rev. 0/pictures/5245_-_installed_via_adapter_SpeedDOS_EPROM.JPG

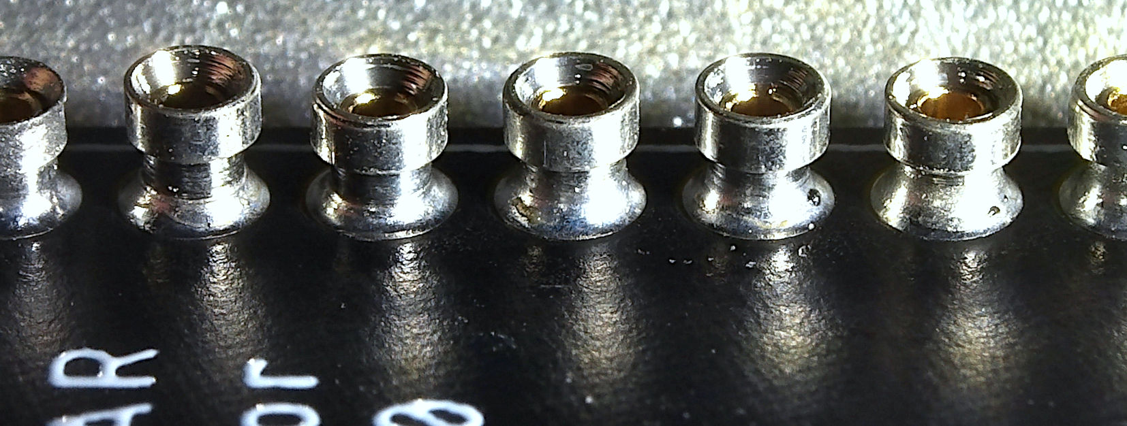
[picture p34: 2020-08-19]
1541_VIA_Parallel_Adapter_lowP/Rev. 0/pictures/002_-_soldered_sockets_PCB_top.JPG

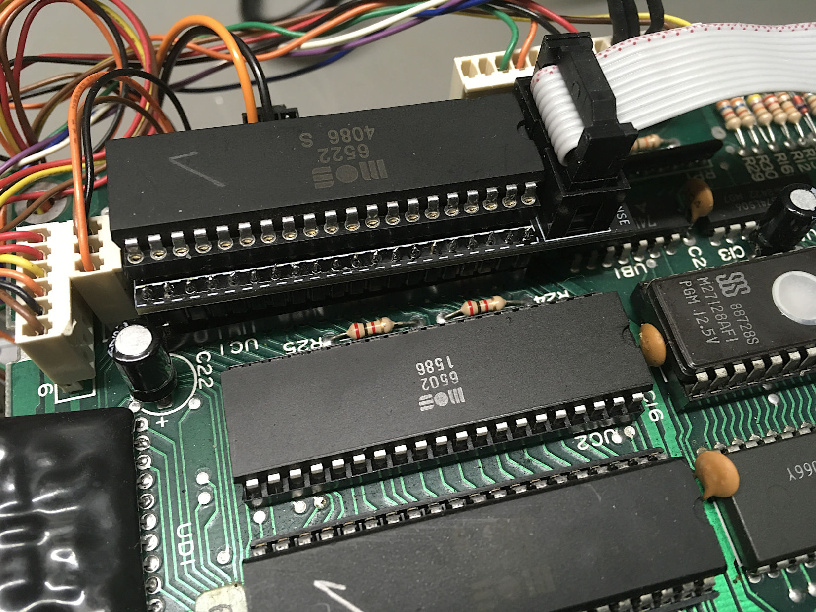
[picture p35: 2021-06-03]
1541_VIA_Parallel_Adapter_1541C/Rev. 0/pictures/8380_-_Installation_1541C_closeup.JPG

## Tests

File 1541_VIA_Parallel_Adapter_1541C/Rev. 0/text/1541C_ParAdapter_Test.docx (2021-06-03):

Commodore 1541 VIA/Parallel-Adapter for 1541C Rev. 0

Testing

# Test Setup

- VIA/Parallel-Adapter for 1541C Rev. 0
- 1541C (not operational) for mechanical testing
- 1541 with SpeedDOS Kernal v2.7
- C64 with SpeedDOS v2.7
- User Port Parallel Adapter for the 1541/1541-II Rev. 0

# Test Execution

The Parallel Adapter for the Commodore 1541C was installed in a 1541C. It has fit without a problem and no (mechanical) modifications of the drive have been required.

The strain relief of the (2x5) IDC ribbon cable header has been slightly too high. While closing the case of the 1541C, the adaptor was dislocated. It is required to install the parallel cable without this strain relief.


Figure 1: Installation in a 1541C

Due to a lack of a working 1541C, the adapter was installed in a 1541. Since it is not designed to fit into the 1541, a DIP40 socket was required to fit the adapter for the test. Closing the lid of the 1541 was not possible, but this is not withing the scope of this development.

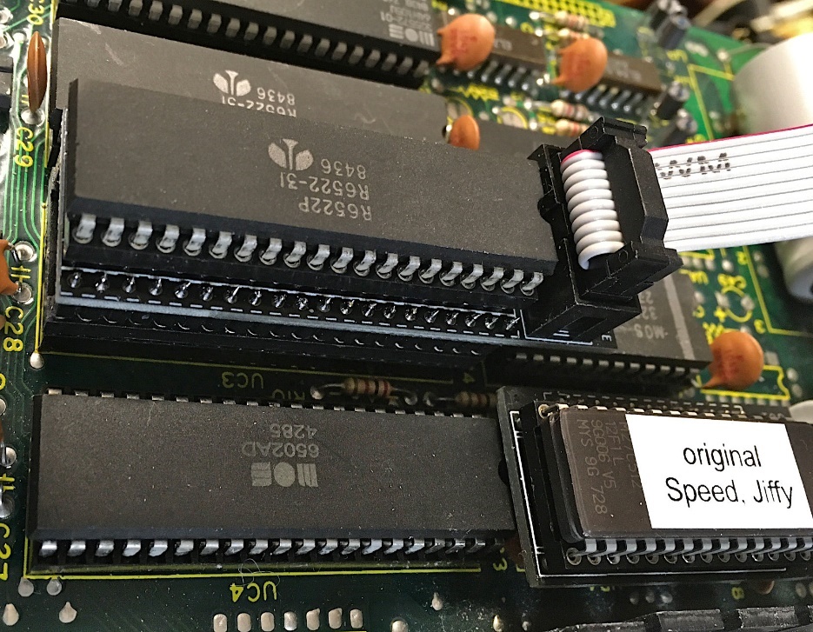
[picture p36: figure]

Figure 2: Installation in a 1541 for electrical testing

The game “Vengeance” was loaded from floppy disk with the parallel cable connected to the C64 via the User Port parallel adapter. This required 22.8 seconds.

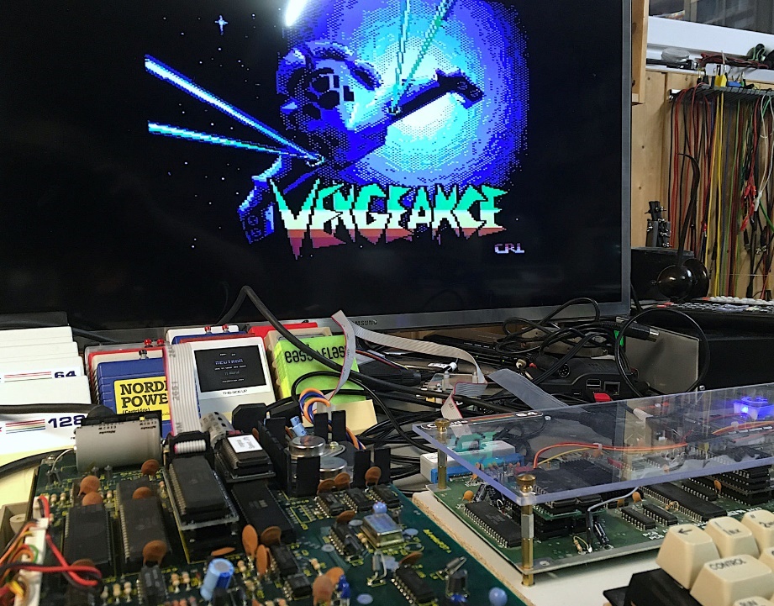
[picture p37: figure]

Figure 3: Loading Vengeance

Now, the parallel cable was disconnected and both SpeedDOS Kernals (1541 and C64) were replaced by the original Commodore Kernals.

Loading “Vengeance” required 160.2 seconds (7 times as long).

# Conclusion

The final test in a 1541C has still to be conducted, but the likelihood is close to 100%, that this will work. Probably, the jumper JP1 has to be opened.

1541C_ParAdapter_Test.docx 07.05.2021 16:33 Drafted by Sven Petersen Page 2 of 2 Doc.-No.: 178-6-02-00

1541C_ParAdapter_Test.docx 07.05.2021 16:33 Drafted by Sven Petersen Page 1 of 1 Doc.-No.: 000-6-00-00

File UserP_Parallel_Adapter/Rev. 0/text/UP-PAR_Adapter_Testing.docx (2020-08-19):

User Port/Parallel Adapter for Commodore 1541/1541-II Rev. 0

Testing

# Test Setup

The tests were conducted with both a Commodore 1541 and a 1541-II and a C64 ASSY 250425 with SpeedDOS 2.7+ Kernal (Figure 1). The 1541 had a SpeedDOS 2.7 installed, the 1541-II required an EPROM (27C128) with SpeedDOS 2.7. Later, the tests were also conducted with a C64 ASSY 250469 (short board) with a SpeedDOS 2.7 Kernal and a 1541 that originally did not have the SpeedDOS Kernal. An EPROM with the original Kernal and SpeedDOS 2.7 (for 1541) was installed on the long board Kernal adapter along with the original 1541 Kernal.

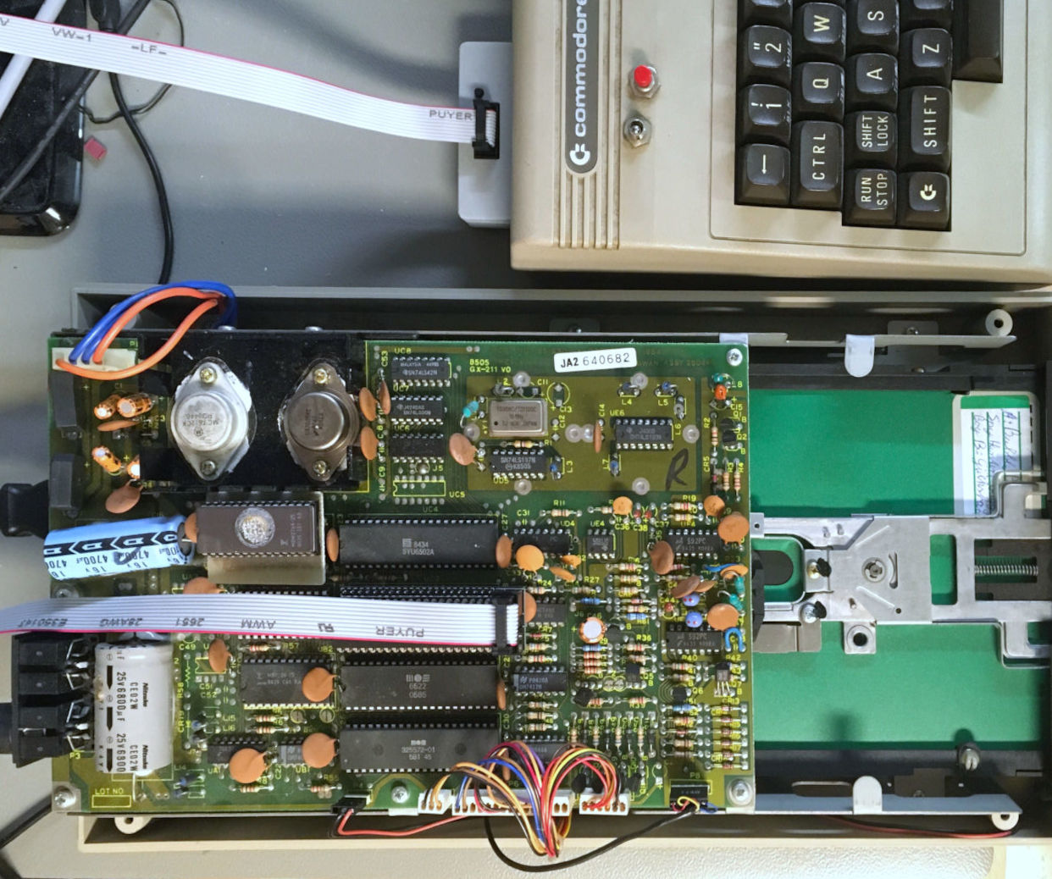
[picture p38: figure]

Figure 1: Test Setup

# Test Procedures

The drive was connected via the serial cable, the parallel cable remained unconnected. Both, the drive and the C64 were switched on. The drive could be accessed. The status was reported as “73, SPEEDDOS 2.7 1541,00,00”. The directory of the disk could be displayed properly and the program “Bubble Bobble” was loading properly in 1minute 54 seconds.

The setup was switched off and the parallel cable was connected to the User Port Parallel Adapter, which was connected to the user port.

After switching on the test setup again, the status was reported correctly, the directory was displayed properly and the program “Bubble Bobble” was loading within about 16.8 seconds.

Clearly, the parallel transmission has reduced the loading time of “Bubble Bobble” to 15%.

Several programs were loaded successfully with the SpeedDOS parallel setup.

A 2nd 1541 drive was equipped with a SpeedDOS-Kernal and the parallel cable (Figure 2). The drive was connected to an ASSY 250469 short board. The previous tests were conducted successfully with the new setup.

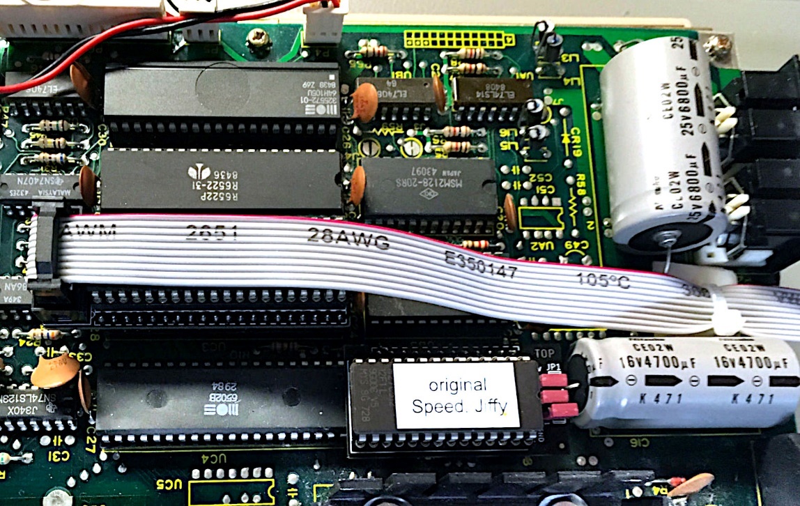
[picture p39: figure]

Figure 2: VIA adapter and a SpeedDOS EPROM (on adapter board)

After the low-profile VIA Parallel Adapter was finally working, the tests were conducted with a 1541-II drive (Figure 3) and the ASSY250425 C64.

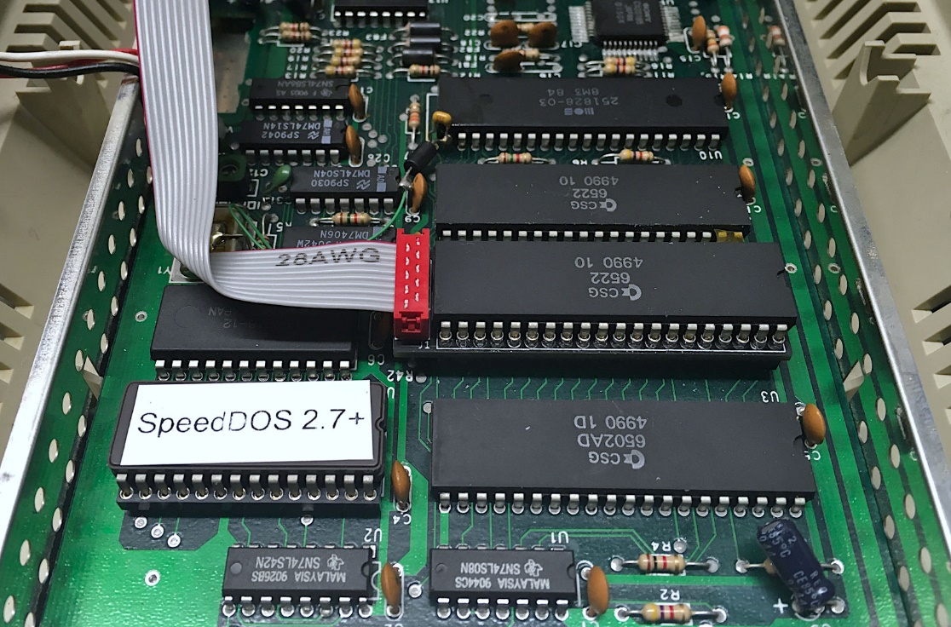
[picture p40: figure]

Figure 3: SpeedDOS Setup in a 1541-II

# Conclusion

The User Port Parallel adaptor in conjunction with both VIA Parallel adaptors are fully functional.

UP-PAR_Adapter_Testing.docx 19.08.2020 10:38 Drafted by Sven Petersen Page 2 of 2 Doc.-No.: 150-6-02-00

UP-PAR_Adapter_Testing.docx 19.08.2020 10:38 Drafted by Sven Petersen Page 1 of 1 Doc.-No.: 150-6-01-00

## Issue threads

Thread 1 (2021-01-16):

Dual drive setup

Obiwantje, 2021-01-16:
Sven, would you mind expanding the PCB for allowing a second drive please?

svenpetersen1965, 2021-01-16:
Hi,
How does that work? The same connector on the user port adapter twice? Actually, you could add a third  connector on the ribbon cable, that is a box connector. I think, something like this is available.

€ 3,36 | 10Pcs / Lot 2.54mm Pitch 2x5 Pin 10 Pin Male Straight IDC Box Header Cable Connector
https://star.aliexpress.com/share/share.htm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

Mit freundlichen Grüßen/Kind regards
Sven

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

The-Spirit, 2021-01-18:
Hi Sven,
SpeedDos Plus had an option to connect 2 drives on the userport
https://www.c64-wiki.de/wiki/Datei:SpeedDOS-plus-Anschluss.jpg
I don't know if there is somebody out there who can provide a schema of that board.
Maybe is there someone who has some code (disk-copier?) that reveals how this works.

Kind regards,
Maurice

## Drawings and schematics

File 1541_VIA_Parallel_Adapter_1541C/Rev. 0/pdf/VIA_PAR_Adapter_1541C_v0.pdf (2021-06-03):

# Project Documentation

## Commodore 1541 VIA/Parallel-Adapter

## Project number: 178

## Revision: 0

## Date: 10.04.2021

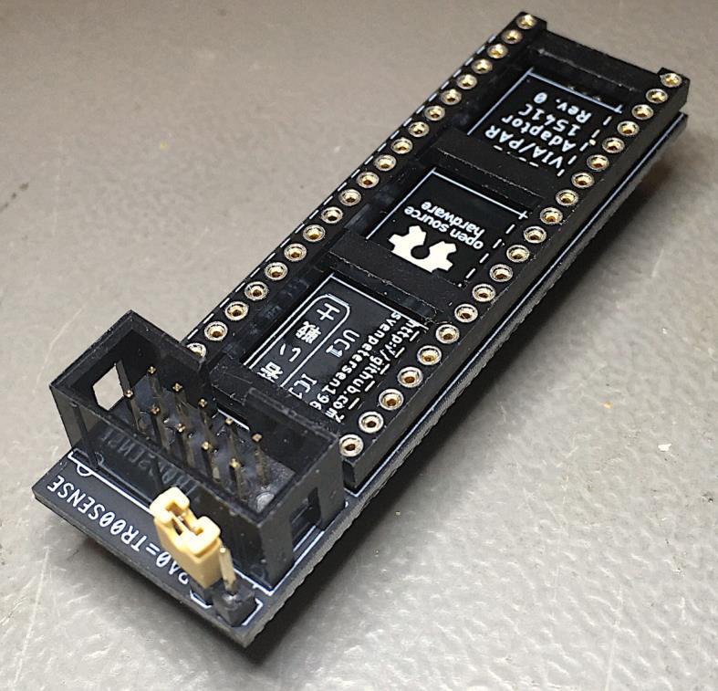
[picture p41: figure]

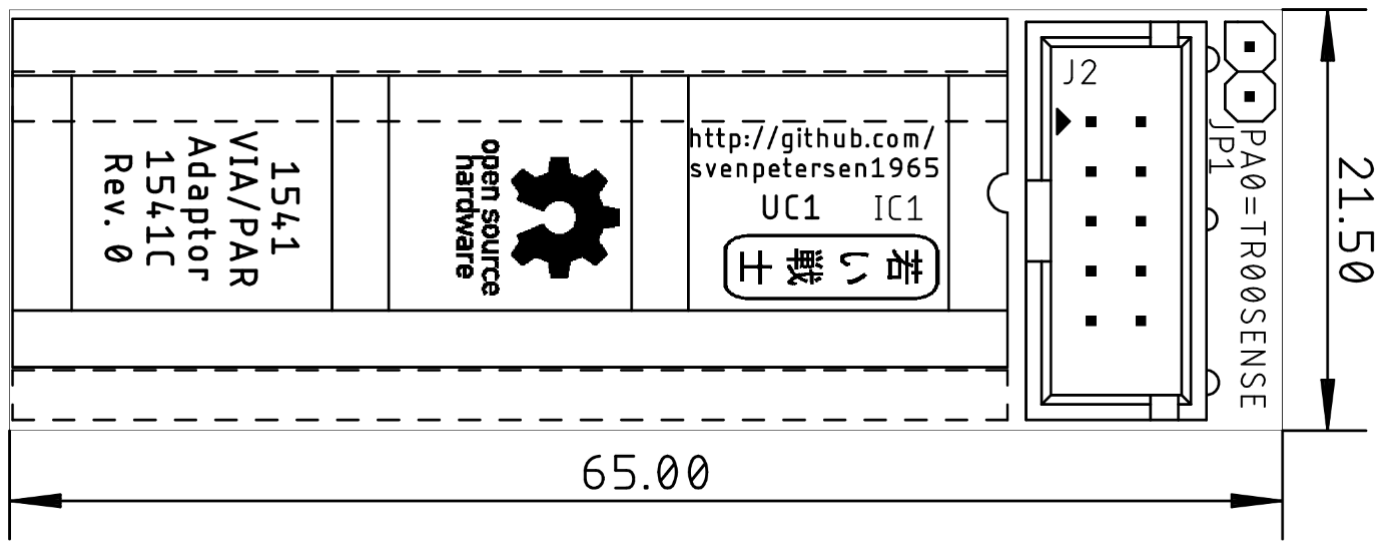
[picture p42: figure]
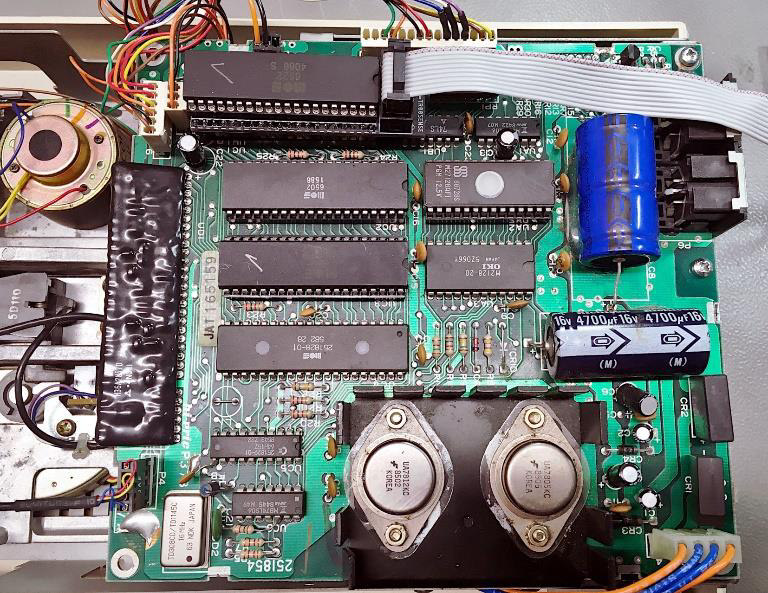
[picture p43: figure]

1541C_ParAdapter_ModD.docx | | 07.05.2021 16:39
Drafted by Sven Petersen | Page 1 of 2 | Doc.-No.: 178-6-01-00

### Commodore 1541 VIA/Parallel-Adapter for 1541C Rev. 0

### Module Description

## Introduction

This adapter board serves as a VIA (6522) adapter for a parallel connection for SpeedDOS in conjunction with a suitable ribbon cable and the User Port Parallel-Adapter (Project 150).

Figure 1: Dimensions

The box connector (2x5 way, 2.54mm pitch) has the following pinout:

VIA (pin) J2 | J2 VIA (pin)
CA2 (39) | 1 | 2 | PA0 (2)
PA1 (3) | 3 | 4 | PA2 (4)
PA3 (5) | 5 | 6 | PA4 (6)
PA5 (7) | 7 | 8 | PA6 (8)
PA7 (9) | 9 | 10 | CB1 (18)
The via for the parallel data transmission in a 1541C is UC1. The Jumper JP1 connects the signal PA0 to the signal TR00SENSE, which is (probably) required for the original firmware.

Figure 2: : VIA-Parallel-Adapter installed in a 1541C

1541C_ParAdapter_ModD.docx | | 07.05.2021 16:39
Drafted by Sven Petersen | Page 2 of 2 | Doc.-No.: 178-6-01-00

## Installation

Three issues have to be taken care of, when installing the VIA-Parallel-Adapter:

- The VIA (UC1) should be socketed
- The adapter has to be oriented properly (align the notch of the IC, the adapter and the socket on the 1541C PCB
- The pins of box connector on the solder side must not make contact with any component leads

The latter issue can be caused by the leads of a 100n capacitor, which can be replaced with a smaller, modern capacitor. The adapter has to sit firmly in the socket, though.

The ribbon cable has two 2x5 (ribbon cable) IDC connectors. The one, that goes inside the 1541C is the one without a strain relief. The header connecting to the User Port Adapter does require the strain relief, though.

It is a good idea to secure the ribbon cable with an adhesive cable post and a cable tie for strain relief, after the configuration is fully functional. A ribbon cable exiting the case through the breakout for the fuse is pretty common, I did not experience any problems with it, but one person reported a possible source of problems, here.

An alternative way of exiting the case is the left side of the case. A breakout for the ribbon cable has to be filed into the case, though.

The cable making with IDC connectors does not require any special tools, except a (small) vice for compressing the connector after the ribbon cable was inserted properly. In case you don not feel
comfortable | with | this | work, | consult | this | write | up | about | cable | making:
http://tech.guitarsite.de/cable_making.html#Ribbon%20Cables

## Assembly

The Assembly of the VIA-Parallel-Adapter is fairly simple. The precision round pin headers on the solder side need to be aligned to be straight and in the proper distance. For this purpose, the cut strips have to be inserted into the DIP-socket before soldering. Their alignment needs to be checked. They should be fully inserted into the socket and the PCB should be perpendicular. After soldering the pin stripes, the DIP-40 socket can be removed and soldered in on the top side. Some of soldered pins of the pin strips might require to be shortened. The DIP-40 socket should sit straight on the PCB.

Finally, the box connector can be soldered.

The pins of the precision pin strips are pretty delicate and brittle. They should not be bent much, so care must be taken before and while installing them in the socket of the 1541. Square headers must not be used instead, because those might break the sockets and do not sit well in the socket, either.

## Revision History
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

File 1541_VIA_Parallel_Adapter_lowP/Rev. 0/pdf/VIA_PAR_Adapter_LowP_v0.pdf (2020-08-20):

# Project Documentation

## Commodore 1541 VIA/Parallel-Adapter (low P.)

## Project number: 149

## Revision: 0

## Date: 19.08.2020

### Commodore 1541-II VIA/Parallel-Adapter Rev. 0

### Module Description

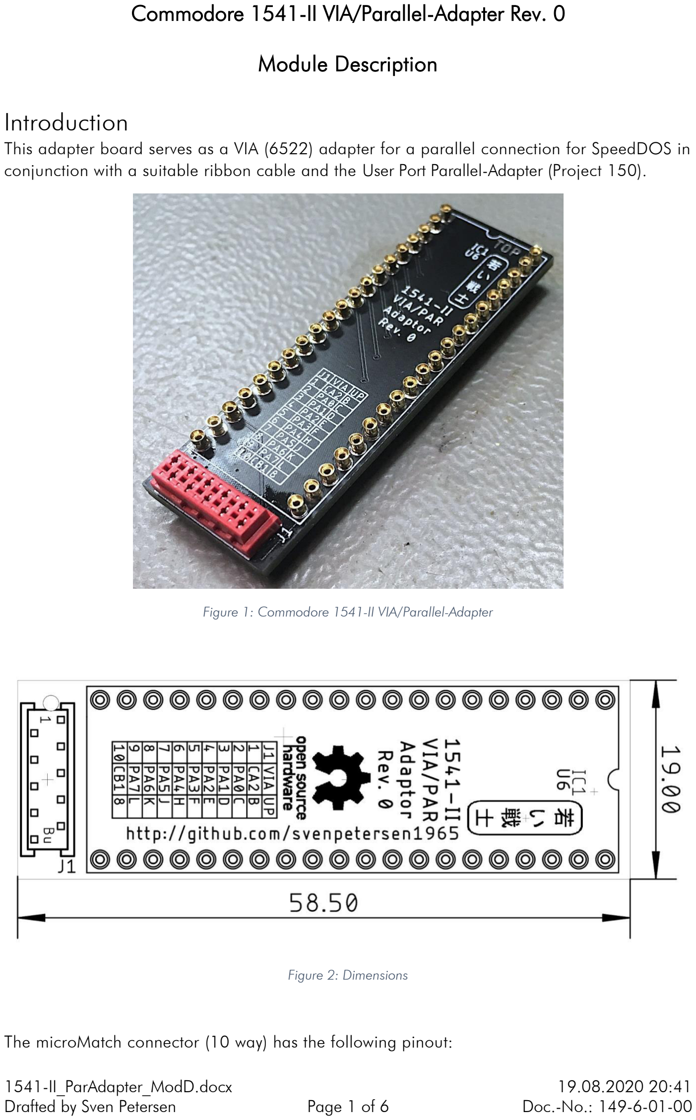
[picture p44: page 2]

1541-II_ParAdapter_ModD.docx | | 19.08.2020 20:41
Drafted by Sven Petersen | Page 1 of 6 | Doc.-No.: 149-6-01-00

## Introduction

This adapter board serves as a VIA (6522) adapter for a parallel connection for SpeedDOS in conjunction with a suitable ribbon cable and the User Port Parallel-Adapter (Project 150).

Figure 1: Commodore 1541-II VIA/Parallel-Adapter

Figure 2: Dimensions

The microMatch connector (10 way) has the following pinout:

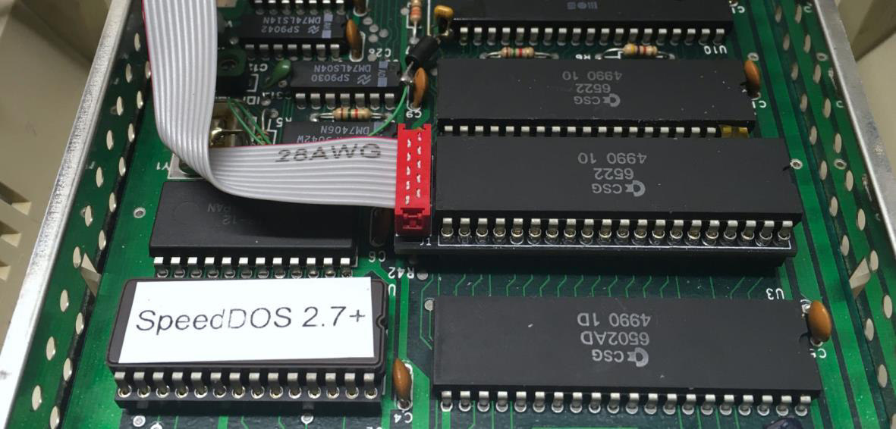
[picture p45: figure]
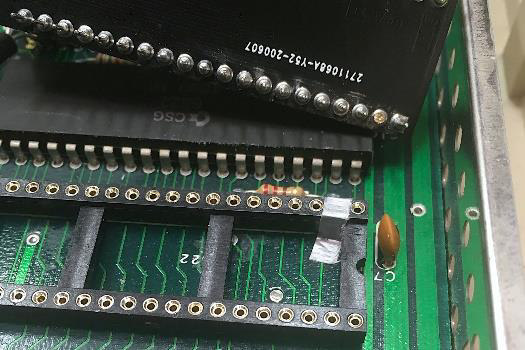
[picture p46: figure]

1541-II_ParAdapter_ModD.docx | | 19.08.2020 20:41
Drafted by Sven Petersen | Page 2 of 6 | Doc.-No.: 149-6-01-00
VIA (pin) J2 | J2 VIA (pin)
CA2 (39) | 1 | 2 | PA0 (2)
PA1 (3) | 3 | 4 | PA2 (4)
PA3 (5) | 5 | 6 | PA4 (6)
PA5 (7) | 7 | 8 | PA6 (8)
PA7 (9) | 9 | 10 | CB1 (18)

The via for the parallel data transmission in a 1541 is U6.

Figure 3: VIA-Parallel-Adapter installed in a 1541-II

## Installation

Four issues have to be taken care of, when installing the VIA-Parallel-Adapter:

- The VIA (U6) should be socketed
- The adapter has to be oriented properly (align the notch of the IC, the adapter and the socket on the 1541-II PCB
- The pins of microMatch connector on the solder side must not make contact with any component leads.
- Pin 2 (PA0) of U6 is connected to GND, which is not required for proper operation (not even with the original Kernal!). This prevents a proper function of the parallel adapter. Pin 2 must either be cut off, filed down (a bit) and insulated (Figure 4) or the trace between pin 1 and pin 2 of U6 must be cut.

Figure 4: Shortened pin 2 and insulated socket

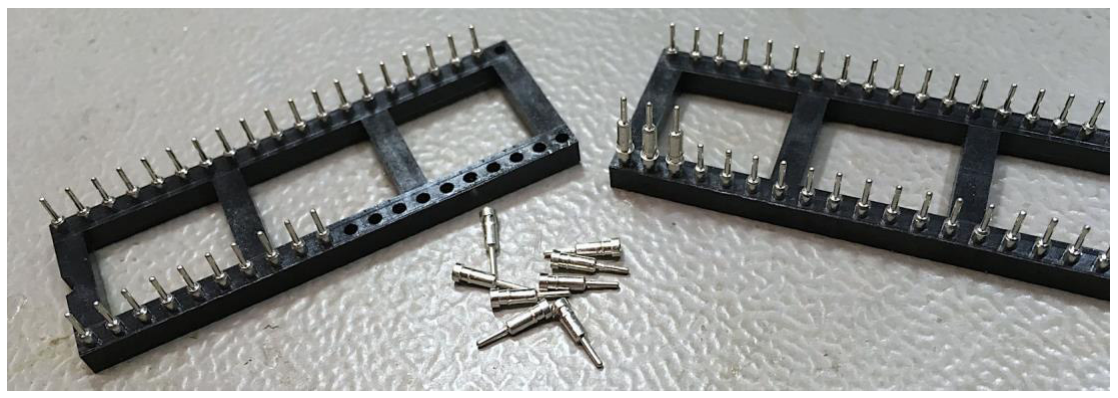
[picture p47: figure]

1541-II_ParAdapter_ModD.docx | | 19.08.2020 20:41
Drafted by Sven Petersen | Page 3 of 6 | Doc.-No.: 149-6-01-00

It is a good idea to secure the ribbon cable with an adhesive cable post and a cable tie for strain relief, after the configuration is fully functional. A ribbon cable exiting the case through the breakout for the fuse is pretty common, I did not experience any problems with it, but one person reported a possible source of problems, here.

An alternative way of exiting the case is the left side of the case. A breakout for the ribbon cable has to be filed into the case, though.

The cable making with IDC connectors does not require any special tools, except a (small) vice for compressing the connector after the ribbon cable was inserted properly. In case you don not feel
comfortable | with | this | work, | consult | this | write | up | about | cable | making:
http://tech.guitarsite.de/cable_making.html#Ribbon%20Cables

## Assembly

The low-profile property of the adapter requires precision round pin sockets. They are usually pretty hard to source and expensive. In July 2020, they were about $10 plus shipping for 50 each on Ebay USA. It is pretty cheap and easy to salvage them from a precision pin DIP-40 socket (40 pin sockets for less than $1!). The pin sockets can be popped out of a precision pin socket by applying slight pressure from the bottom side on the “shoulders” of the pin socket with a suitable tweezer (Figure 5). This takes less than 2 minutes per 40 pins.

Figure 5: Salvaging the pin sockets

For proper soldering, the pin sockets need to be aligned. This is accomplished by plugging each on the pin side of a 2nd DIP-40 precision round pin socket (Figure 6). It has t be checked, that all pins are fully inserted. The pins can now be inserted into the solder pads of the PCB from the top side.

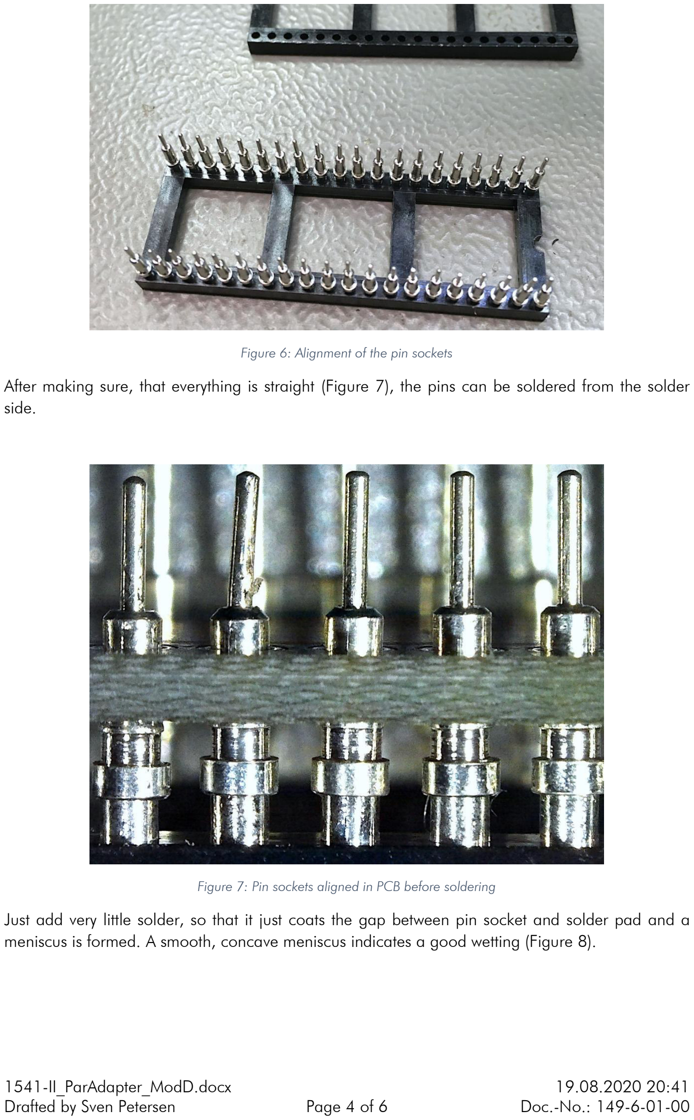
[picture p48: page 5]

1541-II_ParAdapter_ModD.docx | | 19.08.2020 20:41
Drafted by Sven Petersen | Page 4 of 6 | Doc.-No.: 149-6-01-00

Figure 6: Alignment of the pin sockets

After making sure, that everything is straight (Figure 7), the pins can be soldered from the solder side.

Figure 7: Pin sockets aligned in PCB before soldering

Just add very little solder, so that it just coats the gap between pin socket and solder pad and a meniscus is formed. A smooth, concave meniscus indicates a good wetting (Figure 8).

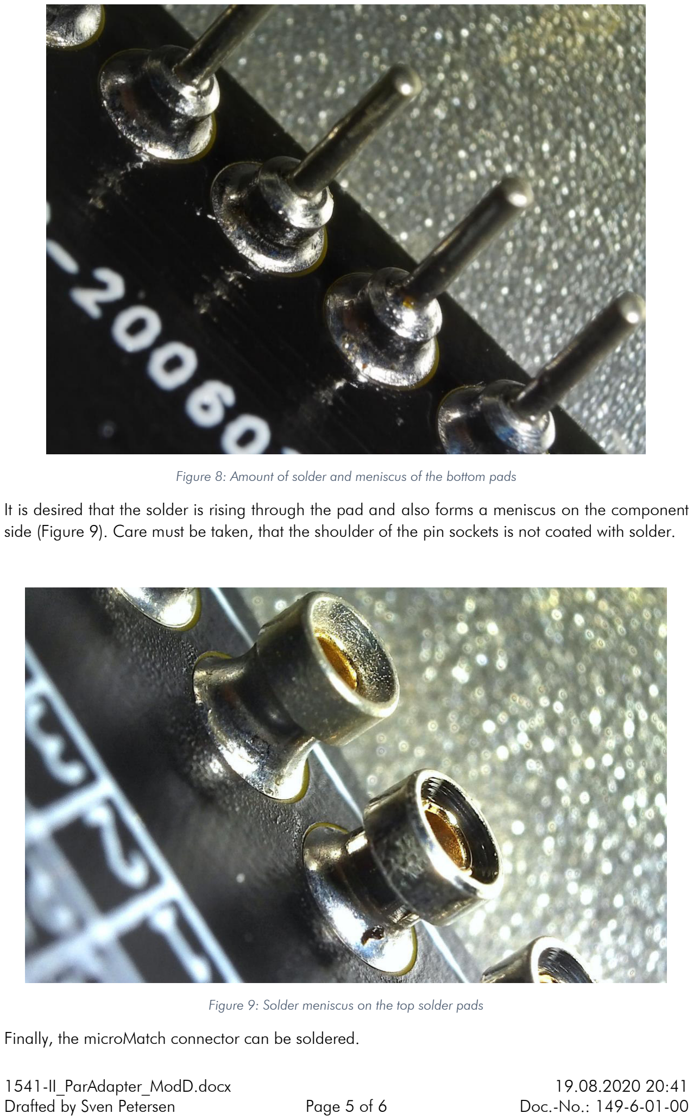
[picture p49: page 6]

1541-II_ParAdapter_ModD.docx | | 19.08.2020 20:41
Drafted by Sven Petersen | Page 5 of 6 | Doc.-No.: 149-6-01-00

Figure 8: Amount of solder and meniscus of the bottom pads
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

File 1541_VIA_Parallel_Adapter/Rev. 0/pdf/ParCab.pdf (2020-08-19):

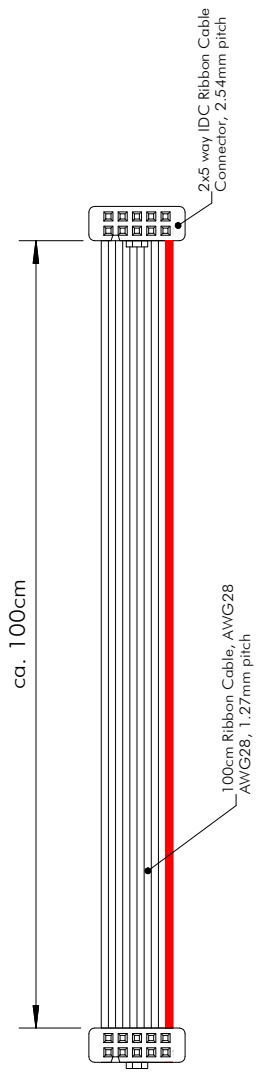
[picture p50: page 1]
Rev.: 0; Datei:; Titel:; Dok.-Nr.: 148-3-01-00; Datum: 18.08.2020 13:56; 100cm Ribbon Cable, AWG28 AWG28, 1.27mm pitch 1

Bearb.: Sven Petersen

1541/Parallel Cable ParCab.SKF 1 2x5 way IDC Ribbon Cable Connector, 2.54mm pitch

https://github.com/svenpetersen1965

VIA-Parallel Adapter

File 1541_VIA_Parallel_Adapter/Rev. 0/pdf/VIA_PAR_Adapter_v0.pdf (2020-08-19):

# Project Documentation

## Commodore 1541 VIA/Parallel-Adapter

## Project number: 148

## Revision: 0

## Date: 19.08.2020

### Commodore 1541 VIA/Parallel-Adapter Rev. 0

### Module Description

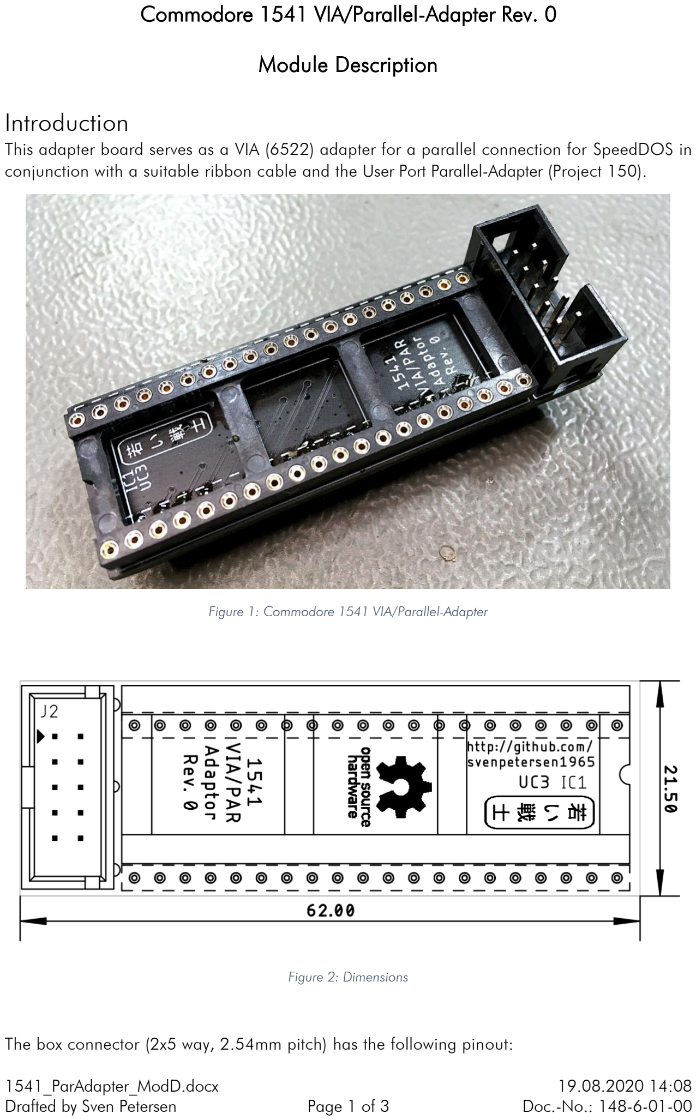
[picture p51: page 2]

1541_ParAdapter_ModD.docx | | 19.08.2020 14:08
Drafted by Sven Petersen | Page 1 of 3 | Doc.-No.: 148-6-01-00

## Introduction

This adapter board serves as a VIA (6522) adapter for a parallel connection for SpeedDOS in conjunction with a suitable ribbon cable and the User Port Parallel-Adapter (Project 150).

Figure 1: Commodore 1541 VIA/Parallel-Adapter

Figure 2: Dimensions

The box connector (2x5 way, 2.54mm pitch) has the following pinout:

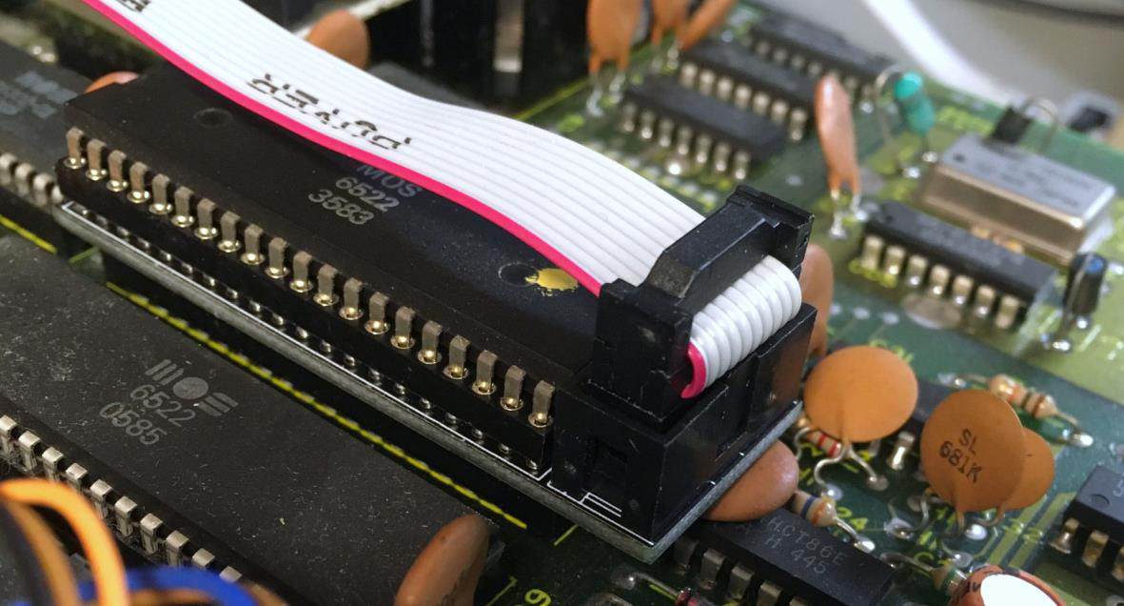
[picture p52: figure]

1541_ParAdapter_ModD.docx | | 19.08.2020 14:08
Drafted by Sven Petersen | Page 2 of 3 | Doc.-No.: 148-6-01-00
VIA (pin) J2 | J2 VIA (pin)
CA2 (39) | 1 | 2 | PA0 (2)
PA1 (3) | 3 | 4 | PA2 (4)
PA3 (5) | 5 | 6 | PA4 (6)
PA5 (7) | 7 | 8 | PA6 (8)
PA7 (9) | 9 | 10 | CB1 (18)

The via for the parallel data transmission in a 1541 is UC3.

Figure 3: VIA-Parallel-Adapter installed in a 1541

## Installation

Three issues have to be taken care of, when installing the VIA-Parallel-Adapter:

- The VIA (UC3) should be socketed
- The adapter has to be oriented properly (align the notch of the IC, the adapter and the socket on the 1541 PCB
- The pins of box connector on the solder side must not make contact with any component leads

The latter issue can be caused by the leads of C28. This is a 100n capacitor, which can be replaced with a smaller, modern capacitor. In case it is a disc capacitor like in Figure 3, it can be bent over. The adapter has to sit firmly in the socket, though.

Figure 4: Secured ribbon cable

1541_ParAdapter_ModD.docx | | 19.08.2020 14:08
Drafted by Sven Petersen | Page 3 of 3 | Doc.-No.: 148-6-01-00

It is a good idea to secure the ribbon cable with an adhesive cable post and a cable tie for strain relief, after the configuration is fully functional (Figure 4). A ribbon cable exiting the case through the breakout for the fuse is pretty common, I did not experience any problems with it, but one person reported a possible source of problems, here.

An alternative way of exiting the case is the left side of the case. A breakout for the ribbon cable has to be filed into the case, though.

The cable making with IDC connectors does not require any special tools, except a (small) vice for compressing the connector after the ribbon cable was inserted properly. In case you don not feel
comfortable | with | this | work, | consult | this | write | up | about | cable | making:
http://tech.guitarsite.de/cable_making.html#Ribbon%20Cables

## Assembly

The Assembly of the VIA-Parallel-Adapter is fairly simple. The precision round pin headers on the solder side need to be aligned to be straight and in the proper distance. For this purpose, the cut strips have to be inserted into the DIP-socket before soldering. Their alignment needs to be checked. They should be fully inserted into the socket and the PCB should be perpendicular. After soldering the pin stripes, the DIP-40 socket can be removed and soldered in on the top side. Some of soldered pins of the pin strips might require to be shortened. The DIP-40 socket should sit straight on the PCB.

Finally, the box connector can be soldered.

The pins of the precision pin strips are pretty delicate and brittle. They should not be bent much, so care must be taken before and while installing them in the socket of the 1541. Square headers must not be used instead, because those might break the sockets and do not sit well in the socket, either.

## Revision History
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

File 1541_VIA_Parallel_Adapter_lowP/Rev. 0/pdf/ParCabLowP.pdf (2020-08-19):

Rev.: 0; Datei:; Titel:; Dok.-Nr.: 149-3-01-00; Datum: 18.08.2020 13:47; MicroMatch; connector, 10 way; (e.g. TYCO/AMP 8-215083-0,; MPE Garry 369-1-010); 100cm Ribbon Cable, AWG28; AWG28, 1.27mm pitch

1541-II/Parallel Cable ParCabLowP.SKF 1 2x5 way IDC Ribbon Cable Connector, 2.54mm pitch

Bearb.: Sven Petersen

https://github.com/svenpetersen1965

VIA-Parallel Adapter

Nipple marks pin 1

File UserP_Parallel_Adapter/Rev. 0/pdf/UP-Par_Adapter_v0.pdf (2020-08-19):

# Project Documentation

## User Port/Parallel Adapter for Commodore 1541/1541-II

## Project number: 150

## Revision: 0

## Date: 18.08.2020


UP-PAR_Adapter_ModD.docx | | 19.08.2020 10:40
Drafted by Sven Petersen | Page 1 of 3 | Doc.-No.: 150-6-01-00

### User Port/Parallel Adapter for Commodore 1541/1541-II Rev. 0

### Module Description

## Introduction

Some speed-loaders for the C64 make use of a parallel data transfer for communicating with the Commodore 1541 or 1541-II floppy disk drive. This is possible, because in both FDDs a complete port (PAx) and two hand shake pins (CA2, CB1) of the 2nd VIA (6522) are not used.

SpeedDOS utilizes this fact and uses a ribbon cable between the VIA and the User Port.

Very often, the ribbon cable has been attached to an extra DIP40 socket, which it is soldered to, that fits between the original socket and the VIA. This ribbon cable is then connected to an edge connector for the user port. This is a cheap solution, which is not very reliable. A wire can be torn off the socket or the ribbon cable gets old and brittle etc.

Figure 1: Traditional Parallel Cable

The User Port Adapter provides a solution with an easy to make and easy to replace cable. The risk of a wrong assembly is little. It works in conjunction with a dedicated VIA adapter for the 1541 and a low-profile adapter for the 1541-II.

Figure 2: User Port Parallel Adapter and both sorts of VIA Adapters


UP-PAR_Adapter_ModD.docx | | 19.08.2020 10:40
Drafted by Sven Petersen | Page 2 of 3 | Doc.-No.: 150-6-01-00

The connections between the user port and the VIA for SpeedDOS are defined like this:

UP (pin) VIA (pin) J2 | J2 VIA (pin) UP (pin)
FLAG2 (B) | CA2 (39) | 1 | 2 | PA0 (2) | PB0 (C)
PB1 (D) | PA1 (3) | 3 | 4 | PA2 (4) | PB2 (E)
PB3 (F) | PA3 (5) | 5 | 6 | PA4 (6) | PB4 (H)
PB5 (J) | PA5 (7) | 7 | 8 | PA6 (8) | PB6 (K)
PB7 (L) | PA7 (9) | 9 | 10 | CB1 (18) | PC2 (8)

In the 1541, the used VIA is UC3, in the 1541-II, the VIA is U6.

The User Port parallel adapter provides a RESET button and also two capacitors between CA2 and GND and between CB1 and GND. Those capacitors are recommended to improve problems due to crosstalk here: http://pitsch.de/stuff/c64/index_floppy.htm#B1.3.

Crosstalk problems were not experienced while testing without the capacitors, they do not cause problems, either, so they are at least an option.

## Dimensions

Figure 3: Dimensions of the User Port Parallel Adapter


UP-PAR_Adapter_ModD.docx | | 19.08.2020 10:40
Drafted by Sven Petersen | Page 3 of 3 | Doc.-No.: 150-6-01-00

## Case

Figure 4: User Port Adapter in a 3D-printed case

## Annotations

SpeedDOS requires a special Software in the 1541 and 1541-II floppy disk drive. While the 1541-II accepts a 27C128 EPROM, the EPROM of the 1541 is a 2364 type, which requires an adapter. The Long Board Kernal Adapter (https://github.com/svenpetersen1965/C64-Kernal-Adapter-Switch-Long-Board) (https://github.com/svenpetersen1965/C64-Kernal-Adapter-Switch-Long-Board) can serve this purpose. The height is not critical in the 1541, but installing a vertical pin header instead of a 90° type is recommended.

The cable making is pretty simple. Both ends of the cable are connected to IDC type connectors, which means, a small vice is a sufficient tool for attaching the connectors to the ribbon cable. In case you are not familiar with this work, please consult my article about cable making: http://tech.guitarsite.de/cable_making.html#Ribbon%20Cables

## Revision History

### Rev. 0

- Prototype (fully functional)










UP-PAR_Adapter_Testing.docx | | 19.08.2020 10:38
Drafted by Sven Petersen | Page 1 of 2 | Doc.-No.: 150-6-02-00

### User Port/Parallel Adapter for Commodore 1541/1541-II Rev. 0

### Testing
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

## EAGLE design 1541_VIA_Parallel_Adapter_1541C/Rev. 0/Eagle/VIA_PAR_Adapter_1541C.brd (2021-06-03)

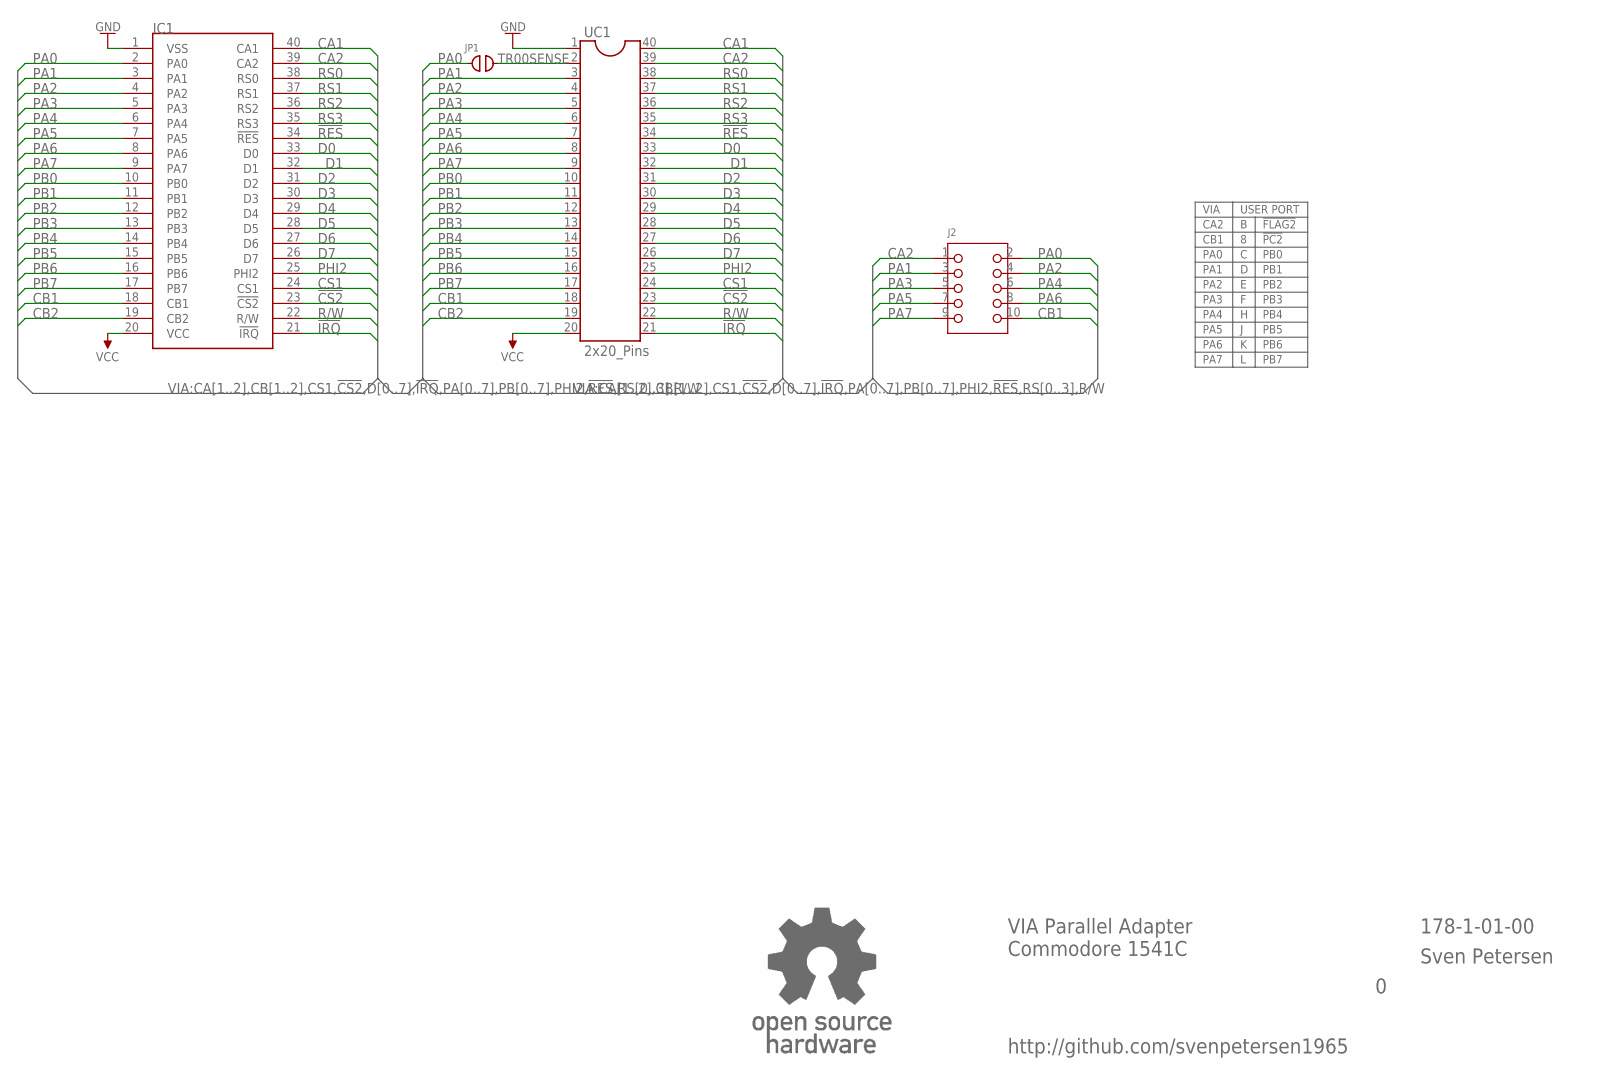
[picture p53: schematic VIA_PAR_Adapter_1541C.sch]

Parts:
IC1: MCS6522SOCKET; GS40P
J2: 2X05WV
JP1: COMBI_2P; COMBI-2P
U$10: OPEN_SOURCE_HW; OPENHW
UC1: 2x20_Pins; DIL40_PINS_SS

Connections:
!CS2: IC1.23 (!CS2), UC1.23
!IRQ: IC1.21 (!IRQ), UC1.21
!RES: IC1.34 (!RES), UC1.34
CA1: IC1.40 (CA1), UC1.40
CA2: IC1.39 (CA2), J2.1, UC1.39
CB1: IC1.18 (CB1), J2.10, UC1.18
CB2: IC1.19 (CB2), UC1.19
CS1: IC1.24 (CS1), UC1.24
D0: IC1.33 (D0), UC1.33
D1: IC1.32 (D1), UC1.32
D2: IC1.31 (D2), UC1.31
D3: IC1.30 (D3), UC1.30
D4: IC1.29 (D4), UC1.29
D5: IC1.28 (D5), UC1.28
D6: IC1.27 (D6), UC1.27
D7: IC1.26 (D7), UC1.26
GND: IC1.1 (VSS), UC1.1
PA0: IC1.2 (PA0), J2.2, JP1.1
PA1: IC1.3 (PA1), J2.3, UC1.3
PA2: IC1.4 (PA2), J2.4, UC1.4
PA3: IC1.5 (PA3), J2.5, UC1.5
PA4: IC1.6 (PA4), J2.6, UC1.6
PA5: IC1.7 (PA5), J2.7, UC1.7
PA6: IC1.8 (PA6), J2.8, UC1.8
PA7: IC1.9 (PA7), J2.9, UC1.9
PB0: IC1.10 (PB0), UC1.10
PB1: IC1.11 (PB1), UC1.11
PB2: IC1.12 (PB2), UC1.12
PB3: IC1.13 (PB3), UC1.13
PB4: IC1.14 (PB4), UC1.14
PB5: IC1.15 (PB5), UC1.15
PB6: IC1.16 (PB6), UC1.16
PB7: IC1.17 (PB7), UC1.17
PHI2: IC1.25 (PHI2), UC1.25
R/W: IC1.22 (R/W), UC1.22
RS0: IC1.38 (RS0), UC1.38
RS1: IC1.37 (RS1), UC1.37
RS2: IC1.36 (RS2), UC1.36
RS3: IC1.35 (RS3), UC1.35
TR00SENSE: JP1.2, UC1.2
VCC: IC1.20 (VCC), UC1.20

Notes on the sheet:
VIA
USER PORT
CA2
CB1
PA0
PA1
PA2
PA3
PA4
PA5
PA6
PA7
!FLAG2
!PC2
PB0
PB1
PB2
PB3
PB4
PB5
PB6
PB7
VIA Parallel Adapter Commodore 1541C
Sven Petersen
178-1-01-00
http://github.com/svenpetersen1965

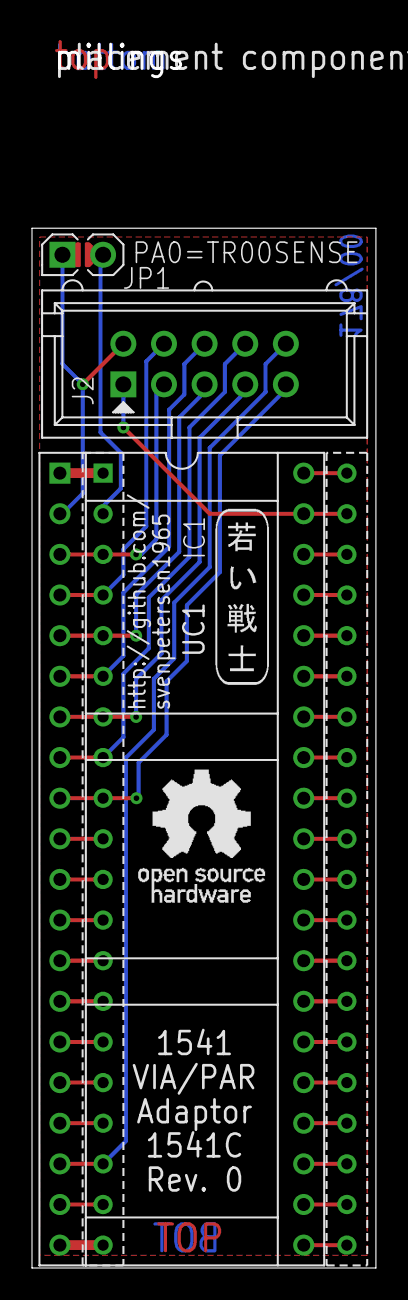
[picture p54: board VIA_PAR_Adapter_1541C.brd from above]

Board: 2 copper layers, 21.5 x 65.0 mm, 8 parts (0 on the bottom side), 41 nets.

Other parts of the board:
U$6: 2LAYER
U$7: PCB-TITLE/
U$8: SVEN_TAG

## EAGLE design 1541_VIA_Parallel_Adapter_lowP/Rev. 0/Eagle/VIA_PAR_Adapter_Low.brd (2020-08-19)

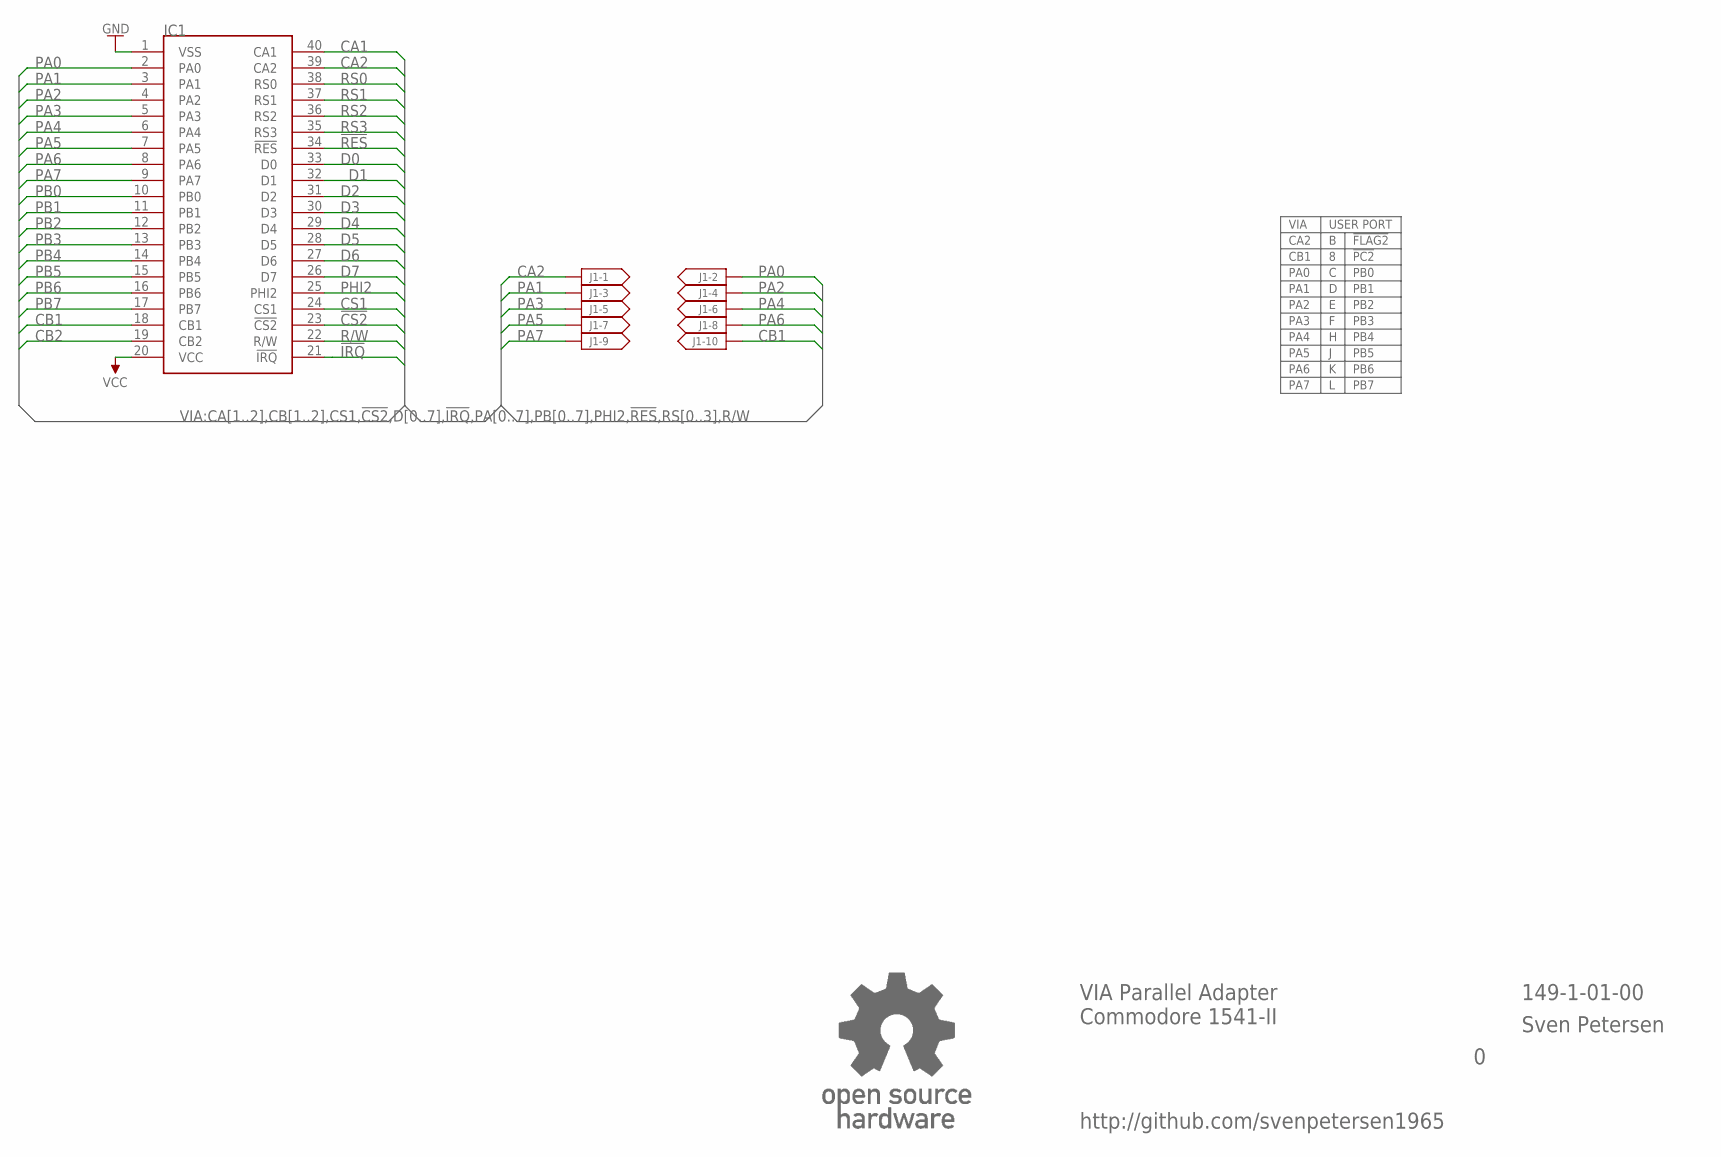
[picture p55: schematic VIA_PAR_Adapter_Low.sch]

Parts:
IC1: MCS6522SOPINS; SOCKETPINS40
J1: MICMA10B-THT; MICMA10B
U$5: OPEN_SOURCE_HW; OPENHW

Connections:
!CS2: IC1.23 (!CS2)
!IRQ: IC1.21 (!IRQ)
!RES: IC1.34 (!RES)
CA1: IC1.40 (CA1)
CA2: IC1.39 (CA2), J1.1
CB1: IC1.18 (CB1), J1.10
CB2: IC1.19 (CB2)
CS1: IC1.24 (CS1)
D0: IC1.33 (D0)
D1: IC1.32 (D1)
D2: IC1.31 (D2)
D3: IC1.30 (D3)
D4: IC1.29 (D4)
D5: IC1.28 (D5)
D6: IC1.27 (D6)
D7: IC1.26 (D7)
GND: IC1.1 (VSS)
PA0: IC1.2 (PA0), J1.2
PA1: IC1.3 (PA1), J1.3
PA2: IC1.4 (PA2), J1.4
PA3: IC1.5 (PA3), J1.5
PA4: IC1.6 (PA4), J1.6
PA5: IC1.7 (PA5), J1.7
PA6: IC1.8 (PA6), J1.8
PA7: IC1.9 (PA7), J1.9
PB0: IC1.10 (PB0)
PB1: IC1.11 (PB1)
PB2: IC1.12 (PB2)
PB3: IC1.13 (PB3)
PB4: IC1.14 (PB4)
PB5: IC1.15 (PB5)
PB6: IC1.16 (PB6)
PB7: IC1.17 (PB7)
PHI2: IC1.25 (PHI2)
R/W: IC1.22 (R/W)
RS0: IC1.38 (RS0)
RS1: IC1.37 (RS1)
RS2: IC1.36 (RS2)
RS3: IC1.35 (RS3)
VCC: IC1.20 (VCC)

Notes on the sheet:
VIA
USER PORT
CA2
CB1
PA0
PA1
PA2
PA3
PA4
PA5
PA6
PA7
!FLAG2
!PC2
PB0
PB1
PB2
PB3
PB4
PB5
PB6
PB7
VIA Parallel Adapter Commodore 1541-II
Sven Petersen
149-1-01-00
http://github.com/svenpetersen1965

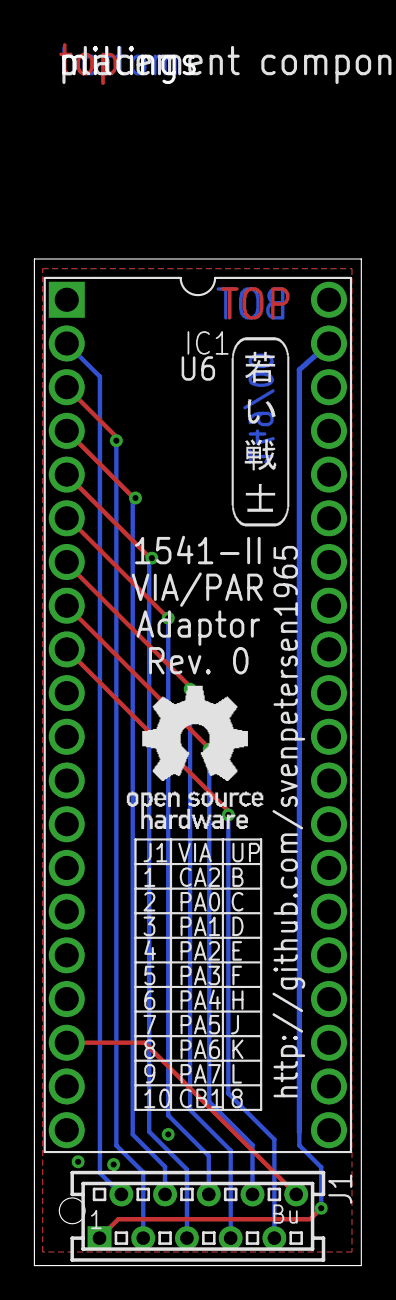
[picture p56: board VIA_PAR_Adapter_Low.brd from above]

Board: 2 copper layers, 19.0 x 58.5 mm, 6 parts (0 on the bottom side), 10 nets.

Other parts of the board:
U$6: 2LAYER
U$7: PCB-TITLE/
U$8: SVEN_TAG

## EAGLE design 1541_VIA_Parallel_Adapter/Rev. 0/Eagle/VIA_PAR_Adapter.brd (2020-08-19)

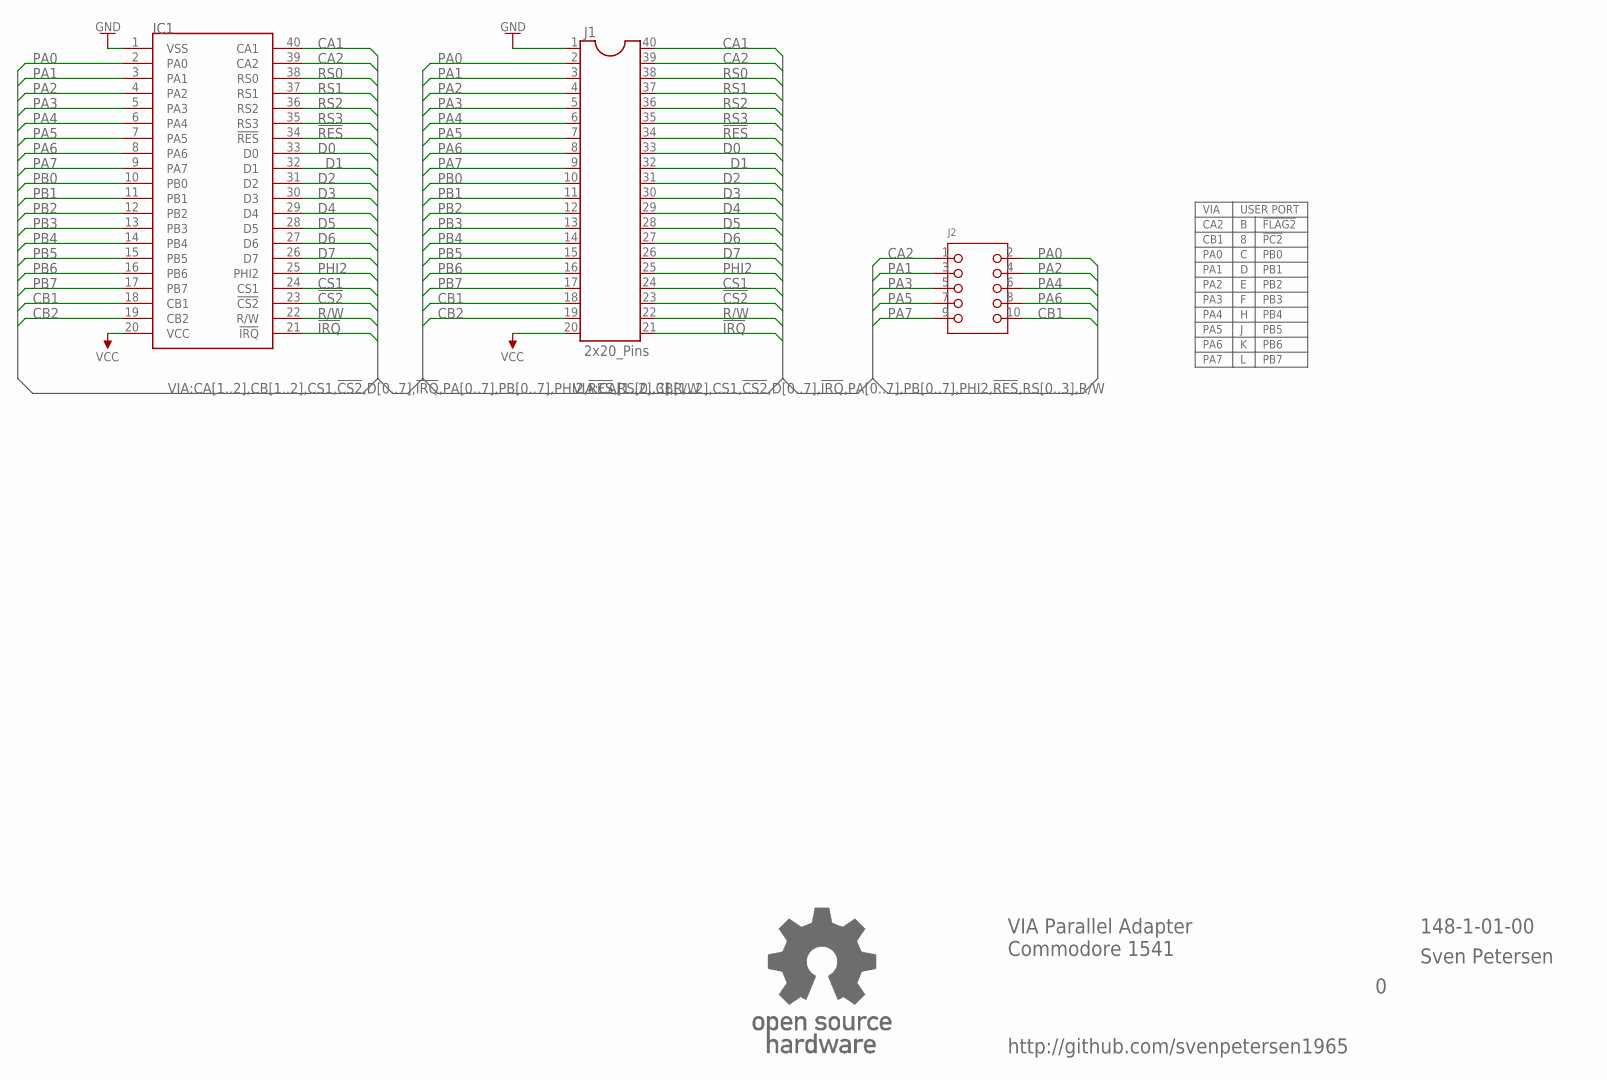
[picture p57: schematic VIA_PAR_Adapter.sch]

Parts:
IC1: MCS6522SOCKET; GS40P
J1: 2x20_Pins; DIL40_PINS_SS
J2: 2X05WV
U$10: OPEN_SOURCE_HW; OPENHW

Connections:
!CS2: IC1.23 (!CS2), J1.23
!IRQ: IC1.21 (!IRQ), J1.21
!RES: IC1.34 (!RES), J1.34
CA1: IC1.40 (CA1), J1.40
CA2: IC1.39 (CA2), J1.39, J2.1
CB1: IC1.18 (CB1), J1.18, J2.10
CB2: IC1.19 (CB2), J1.19
CS1: IC1.24 (CS1), J1.24
D0: IC1.33 (D0), J1.33
D1: IC1.32 (D1), J1.32
D2: IC1.31 (D2), J1.31
D3: IC1.30 (D3), J1.30
D4: IC1.29 (D4), J1.29
D5: IC1.28 (D5), J1.28
D6: IC1.27 (D6), J1.27
D7: IC1.26 (D7), J1.26
GND: IC1.1 (VSS), J1.1
PA0: IC1.2 (PA0), J1.2, J2.2
PA1: IC1.3 (PA1), J1.3, J2.3
PA2: IC1.4 (PA2), J1.4, J2.4
PA3: IC1.5 (PA3), J1.5, J2.5
PA4: IC1.6 (PA4), J1.6, J2.6
PA5: IC1.7 (PA5), J1.7, J2.7
PA6: IC1.8 (PA6), J1.8, J2.8
PA7: IC1.9 (PA7), J1.9, J2.9
PB0: IC1.10 (PB0), J1.10
PB1: IC1.11 (PB1), J1.11
PB2: IC1.12 (PB2), J1.12
PB3: IC1.13 (PB3), J1.13
PB4: IC1.14 (PB4), J1.14
PB5: IC1.15 (PB5), J1.15
PB6: IC1.16 (PB6), J1.16
PB7: IC1.17 (PB7), J1.17
PHI2: IC1.25 (PHI2), J1.25
R/W: IC1.22 (R/W), J1.22
RS0: IC1.38 (RS0), J1.38
RS1: IC1.37 (RS1), J1.37
RS2: IC1.36 (RS2), J1.36
RS3: IC1.35 (RS3), J1.35
VCC: IC1.20 (VCC), J1.20

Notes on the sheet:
VIA
USER PORT
CA2
CB1
PA0
PA1
PA2
PA3
PA4
PA5
PA6
PA7
!FLAG2
!PC2
PB0
PB1
PB2
PB3
PB4
PB5
PB6
PB7
VIA Parallel Adapter Commodore 1541
Sven Petersen
148-1-01-00
http://github.com/svenpetersen1965

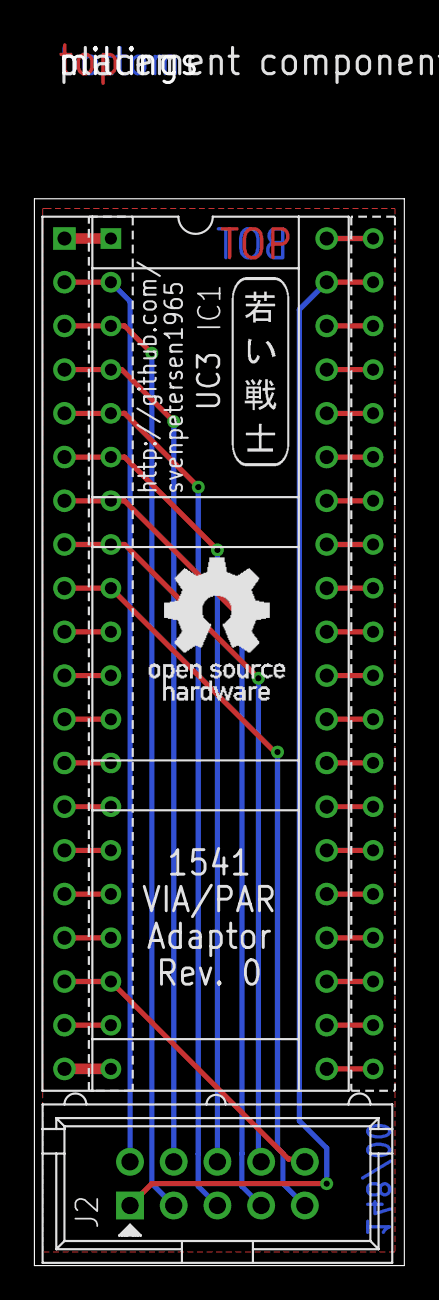
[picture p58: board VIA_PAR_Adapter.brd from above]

Board: 2 copper layers, 21.5 x 62.0 mm, 7 parts (0 on the bottom side), 40 nets.

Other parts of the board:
U$6: 2LAYER
U$7: PCB-TITLE/
U$8: SVEN_TAG

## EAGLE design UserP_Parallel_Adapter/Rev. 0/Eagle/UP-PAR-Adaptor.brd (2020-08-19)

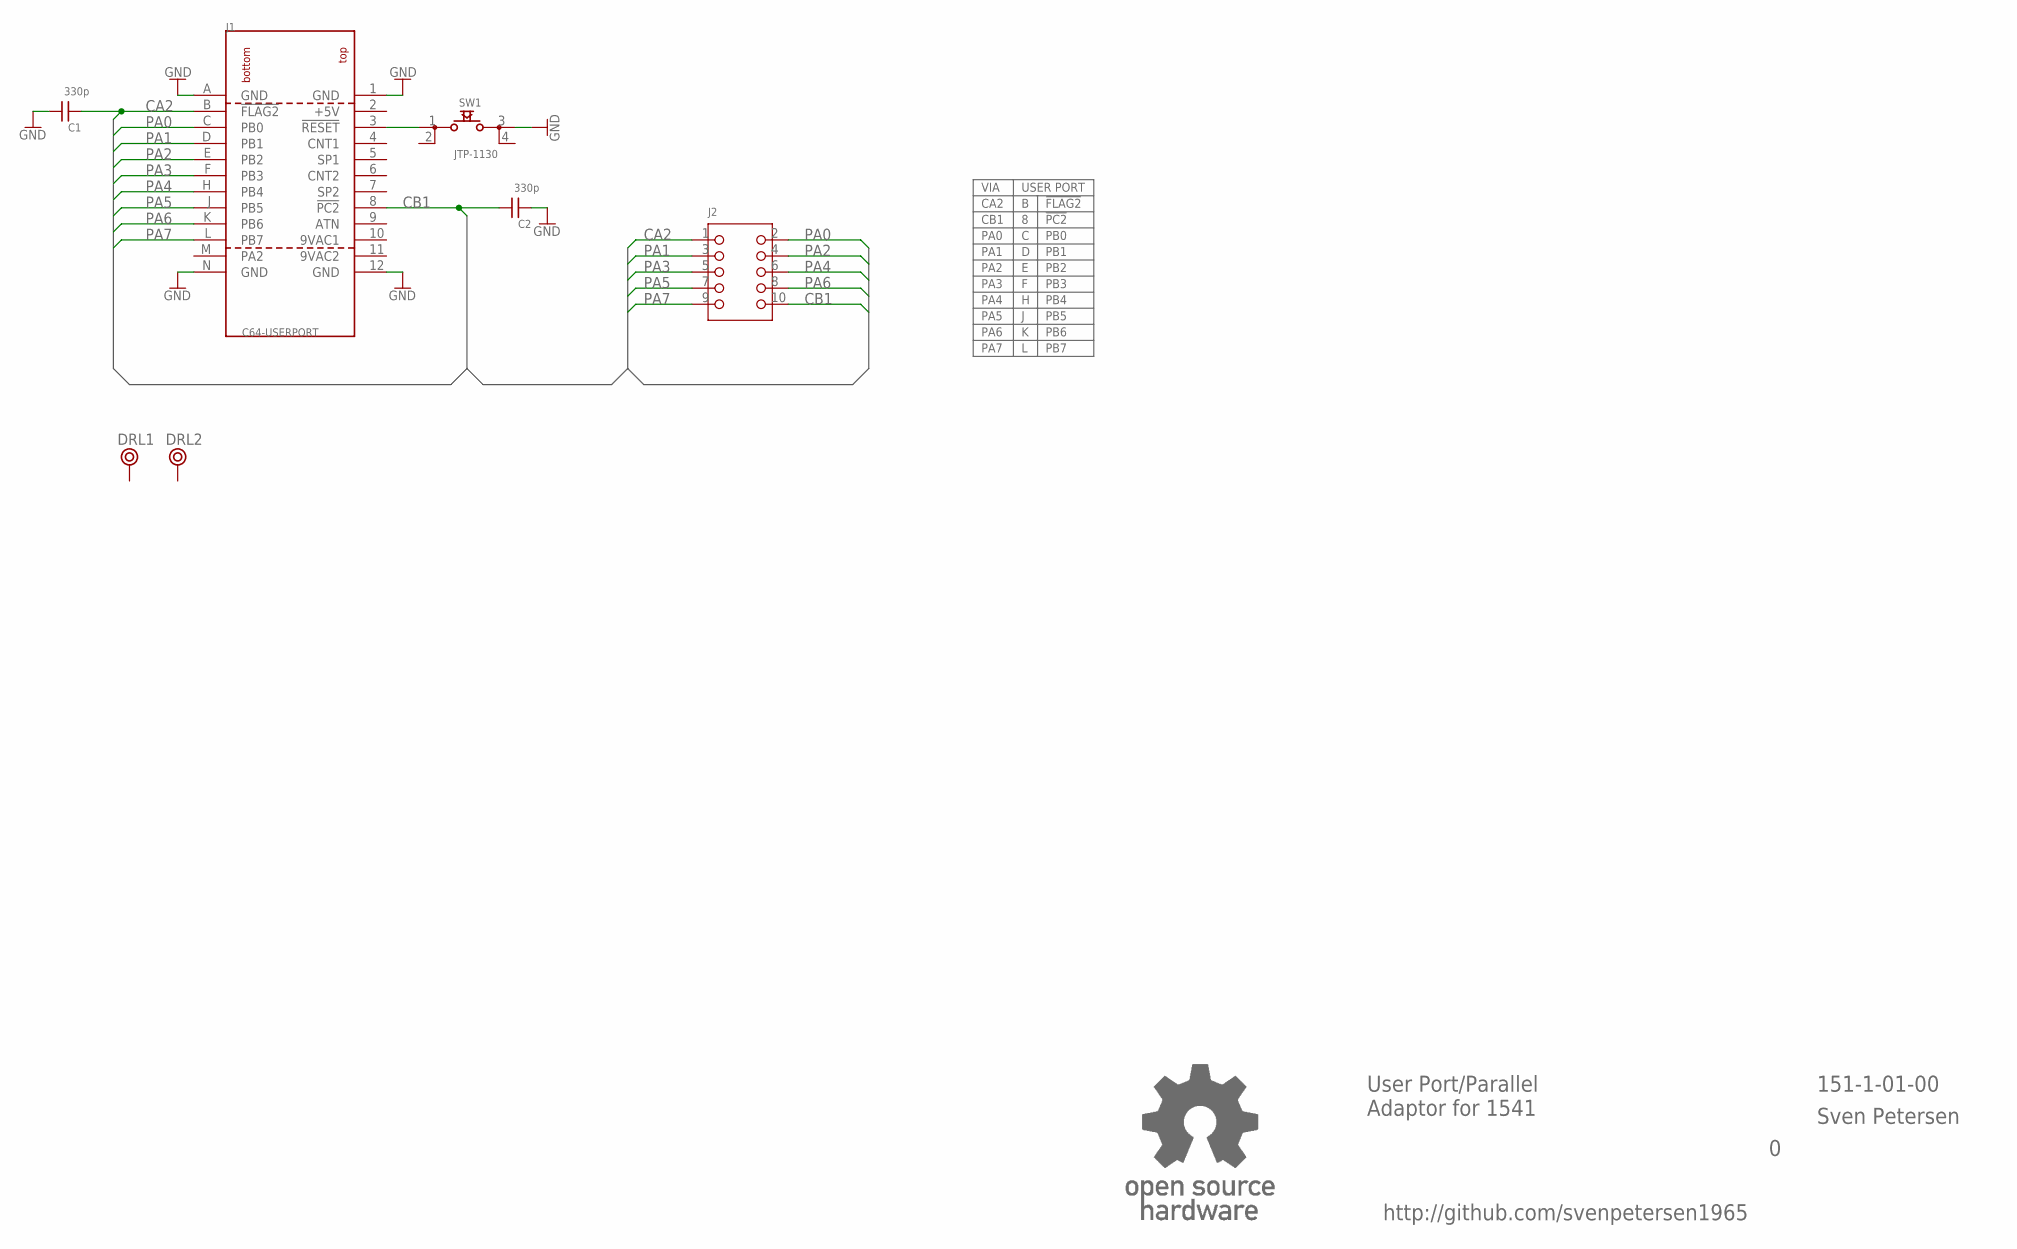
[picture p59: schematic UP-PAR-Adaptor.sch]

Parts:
C1, C2: 330p; C-2,5
DRL1, DRL2: BOHR3,5
J1: C64-USERPORT; USERPORT
J2: 2X05WV
SW1: JTP-1130
U$13: OPEN_SOURCE_HW; OPENHW

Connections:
9VAC1: J1.10 (9VAC1)
9VAC2: J1.11 (9VAC2)
+5V: J1.2 (+5V)
CA2: C1.1, J1.B (!FLAG2), J2.1
CB1: C2.2, J1.8 (!PC2), J2.10
GND: C1.2, C2.1, J1.1 (GND), J1.12 (GND), J1.A (GND), J1.N (GND), SW1.3
unnamed: J1.3 (!RESET), SW1.1
PA0: J1.C (PB0), J2.2
PA1: J1.D (PB1), J2.3
PA2: J1.E (PB2), J2.4
PA3: J1.F (PB3), J2.5
PA4: J1.H (PB4), J2.6
PA5: J1.J (PB5), J2.7
PA6: J1.K (PB6), J2.8
PA7: J1.L (PB7), J2.9

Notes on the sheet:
VIA
USER PORT
CA2
CB1
PA0
PA1
PA2
PA3
PA4
PA5
PA6
PA7
!FLAG2
!PC2
PB0
PB1
PB2
PB3
PB4
PB5
PB6
PB7
User Port/Parallel Adaptor for 1541
151-1-01-00
Sven Petersen
http://github.com/svenpetersen1965

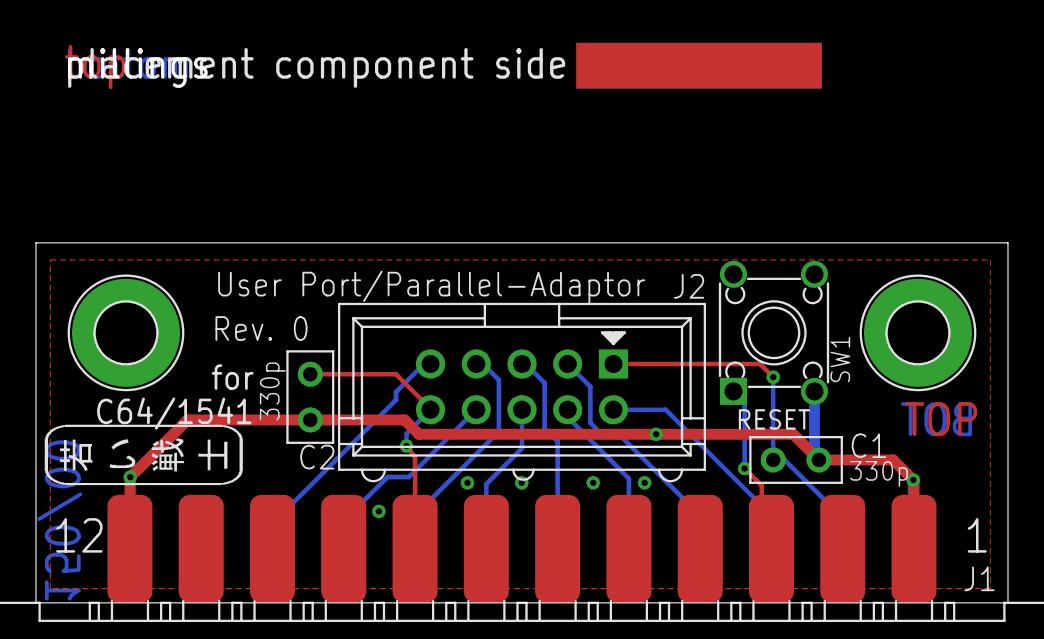
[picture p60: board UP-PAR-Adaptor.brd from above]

Board: 2 copper layers, 54.0 x 20.0 mm, 11 parts (1 on the bottom side), 12 nets.

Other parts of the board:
U$8: 2LAYER
U$9: PCB-TITLE/
U$10: SVEN_TAG

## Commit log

2020-08-19 Initial release
    [SpeedDOS_ParUP v1 Sheet1.dxf, SpeedDOS_ParUP v5.f3d, UP-PAR-Adaptor.brd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]
2020-08-20 Single round pins in BOM
    [VIA_PAR_Adapter_LowP_BOM_v0_0.xlsx]
2021-06-03 Adaper board for 1541C released
    [VIA_PAR_Adapter_1541C.brd, VIA_PAR_Adapter_1541C.sch, VIA_PAR_Adapter_1541C_BOM_v0_0.xlsx]
